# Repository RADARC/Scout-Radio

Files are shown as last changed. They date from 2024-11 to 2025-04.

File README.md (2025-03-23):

# Scout-Radio
Si4732 and Raspberry Pi Pico Radio device for Scouts to build and use to gain badges

Reading and District Amateur Radio Club works withl local Scouts groups and help them in support of their badges and activities

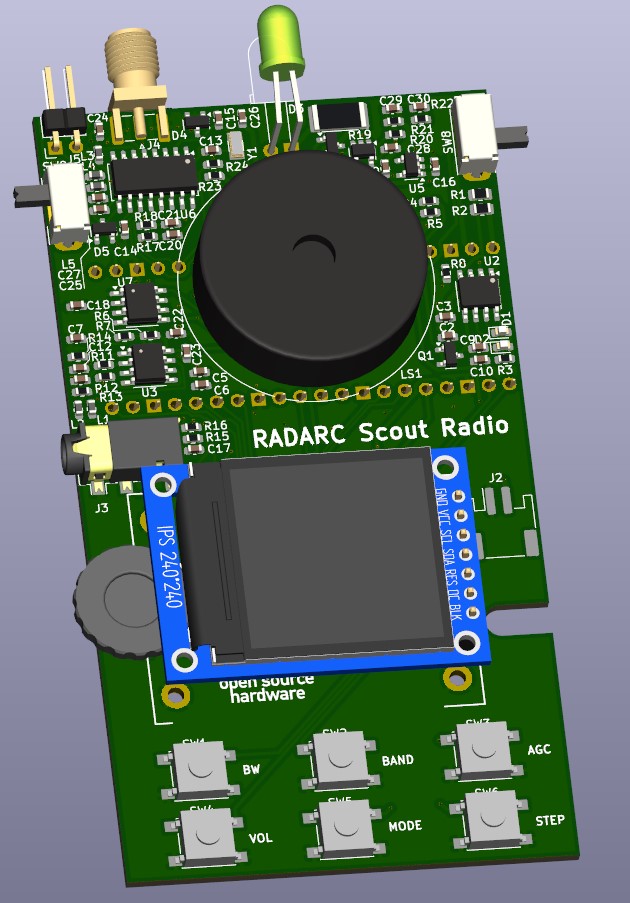
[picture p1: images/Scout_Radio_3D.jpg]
Project Athena 3D


## Objectives:
<ul>
<li>Design and build a radio device with can support Scouts in the following badges
<ul>
<li>[Electronics](https://www.scouts.org.uk/scouts/activity-badges/electronics/)</li>
<li>[Communicator](https://www.scouts.org.uk/scouts/activity-badges/communicator/)</li>
</ul>
<li>Involve Scouts in radio activities</li>
<li>Potential Sponsorship and incresaed local community technology support for Scouts</li>
<li>Interesting Project for RADARC Constructors</li>
<li>Have Fun!</li>
</ul>

## Design Specification
Derived from the RLab Reading Hackspace [Project Athena](https://github.com/reading-hackspace/project-athena)
<ul>
<li>Microprocessor design based on Raspberry Pi Pico Microcontroller</li>
<li>Programmable firmware in CircuitPython and other programming languages via USB</li>
<li>On Board AM and FM Radio</li>
<li>Loudspeaker and audio output</li>
<li>Rotary Encoder and control buttons</li>
<li>Battery powered 3 off AAA, or LiPo with on board charger from USB</li>
<li>Audio output jack</li>
<li>Mixture of surface mount and through hole components. Some components can be factory assembled</li>
<li>Colour LCD display integral</li> 
<li>Optional GPS module</li>
<li>Optional Compass module</li>
<li>Low Cost, under £20</li>
</ul>

## Proposed Design
The following elements are in the prototype design, being commonly available at reasonable cost. Some of these may not be in the final design or optional modules to save cost:

### Raspberry Pi Pico Processor Module
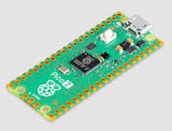
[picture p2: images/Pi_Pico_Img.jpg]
Pi Pico Image


The Raspberry Pi Pico module is based on the RP2040 microprocessor. The module includes flash memory, power supply, crystal clock and a USB interface. It is an easy way to to integrate this processor without detail PCB layout and at attractive cost.
The Pi Pico Module have different variants which are pin compatible. They offer different USB Connectors(Micro-B, USB-C), Wireless and bluetooth integrated, and a higher performance version in the RP2350.
[Pi Pico Data sheet](https://datasheets.raspberrypi.com/pico/pico-datasheet.pdf)

The RP2040 is an ARM Cortex M0+ 32 bit processor which operates at 133MHz and includes a wide range of integrated peripherals.
[RP2040 Data sheet](https://datasheets.raspberrypi.com/rp2040/rp2040-datasheet.pdf)

High quality software support for the RP2040 and Pi Pico Modules is available in C/C++ ([C SDK](https://www.raspberrypi.com/documentation/microcontrollers/c_sdk.html), and [Arduino Pi Pico](https://www.tomshardware.com/how-to/program-raspberry-pi-pico-with-arduino-ide)), and Python([Micropython](https://www.raspberrypi.com/documentation/microcontrollers/micropython.html), and [CircuitPython](https://circuitpython.org/board/raspberry_pi_pico/))

### SiLabs Si4732 AM/FM radio
[Datasheet](https://www.skyworksinc.com/-/media/Skyworks/SL/documents/public/data-shorts/Si4732-A10-short.pdf)

The Si4732 is an integrated AM/FM radio device which is digitally programmable over I2C.
It covers a range of frequencies:
<ul> 
<li>Worldwide FM band support (64–108 MHz) </li>
<li>Worldwide AM band support (520–1710 kHz)</li>
<li>SW band support (2.3–26.1 MHz)</li>
<li>LW band support (153–279 kHz)</li>
</ul>
The radio also supports FM stereo and RDS.
Software patches are available for the device to support SSB and NBFM

### Rotary Encoder and push button controls

A side operated rotary encoder is installed on the prototype, but we might look at lower cost alternatives. There are 6 tactile push button switches which can be used to invoke the various radio functions. These controls can also be used to play simple nintendo like games on the radio.

### Audio Output
The stereo audio audio output from the radio chip is amplified to provide an output to headphones of external speakers. This is then further amplified to drive an on board loudspeaker.
The output from the radio chip is also fed to the ADC inputs on the Pi Pico to enable the Pi Pico to provide USB or Bluetooth feed to an external program such as WSJT-X. The Pi Pico may be able to decode locally digital protocols such as FT8 and display locally.
The Pi Pico also provides a PWM audio output for beeps, morse code, and music for simple games.

### 1.3 inch IPS Colour LCD Display
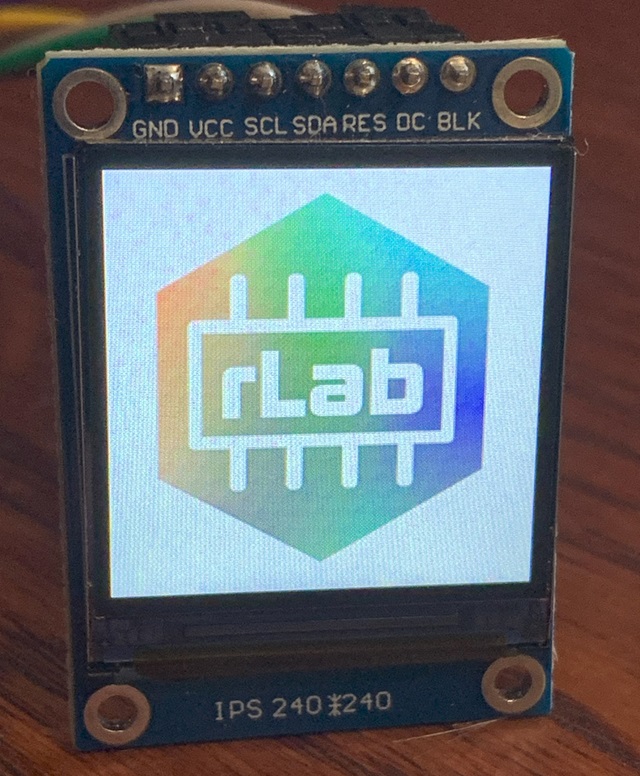
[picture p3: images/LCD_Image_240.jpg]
LCD Image


A colour LCD display was chosen for the device. Limited space allows for a [240 by 240 pixel 1.3 inch IPS display](https://www.smart-prototyping.com/1_3-inch-TFT-IPS-Display-Module-ST7789-SPI-240-240).
The module is based on the ST7789 display IC and is supported by both Micropython and CircuitPython grahics libraries.

### Torch

A high intensity white LED is provided under processor control to be used as a torch or for visual signalling.

### Compass Option
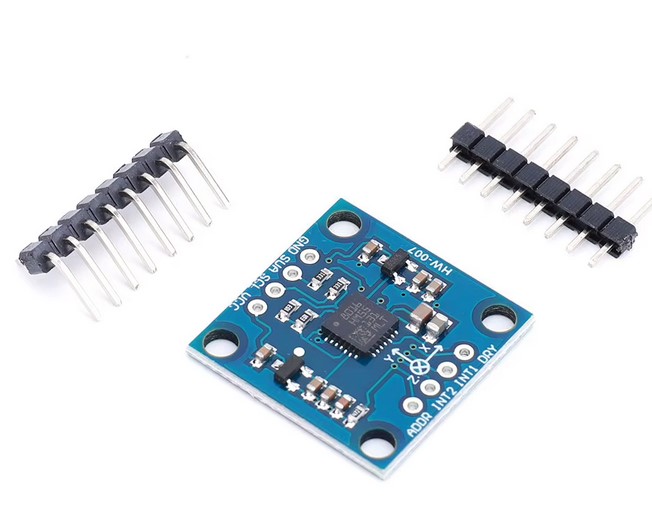
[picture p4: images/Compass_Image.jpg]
Compass Image


An optional compass module based on the LSM303 magnetometer, Compass and accelerometer device can be fitted.

### GPS Option
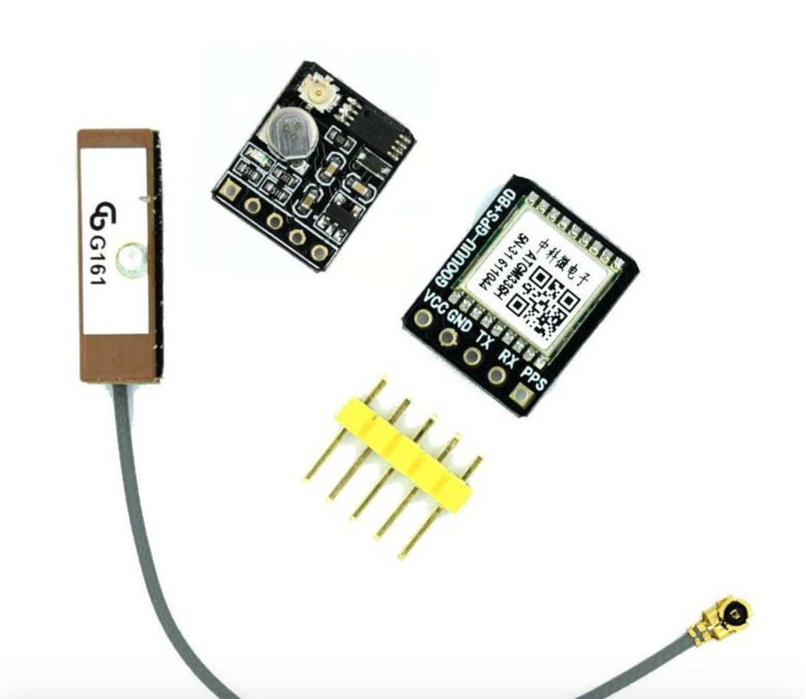
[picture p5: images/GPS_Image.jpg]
GPS Image


An optional GPS module based on the ATGM336H GPS receiver can be fitted 

## Costs
The following costs are based on the JLCPCB prototype build of five units.
All costs are in UK pounds and include shipping and taxes

### Component Costs
| Item | Cost £ |
|---|---|
|Placed components| 8.68| 
|Unplaced components| 8.44|
||--------|
|Total £| 17.12|

The above component cost includes PCB, SMT components, Pi Pico, display and all switches and connectors. I does not include a case.
The placed components were placed by JLCPCB. This cost is dominated by the radio chip and rotary encoder, better sourcing could easily get the component cost under £15.

### Optional Components
| Item | Cost £ |
|---|---|
|LiPo Battery | 2.1|
|SMA antenna| 2.59|
|Compass module| 2.75|
|GPS Module|  2.92 |

### Build Costs
The build costs are again based on the five off prototype, so maybe not very representative of a larger batch. I excluded from the build the through hole components to save cost, also a couple of components that they did not have in stock.
Build costs are driven by a mix of fixed costs per order, setup, solder stencil, etc. Also Costs per board and joint.There are then costs related to what components are used. Common components are already mounted on the pick and place machine and have low cost per component ( fraction of cent). Less common components are often low cost, but we pay $3 per component type to load the component spool to the pick and place, this cost often dominates the assembly costs.
Assembly of through hole components and components and edge mounted components is possible but would attract increased cost.

For the five prototypes:

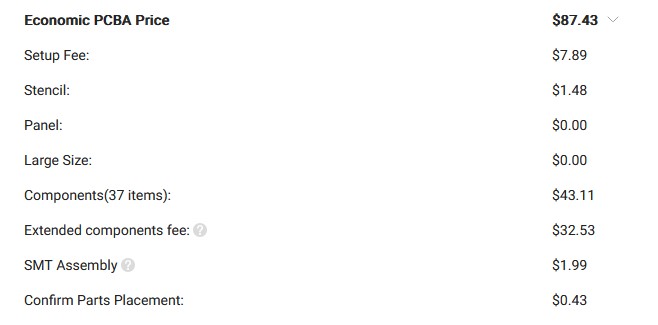
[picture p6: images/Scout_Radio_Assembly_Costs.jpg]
Assembly Pricing


The placed component costs can be excluded, so $44.32 for five. With tax and shipping this is £11.08 per board. Rather expensive at prototype level, but for for a decent board volume (25) when I run through the pricing calculator I get £2.20 per board.

## PCB Files

## Installing Software
``` reinstallsys.sh ```
installs a system from scratch including Circuit Python. Runs on linux only atm.

## Software Project Plan, 12th March 2025.
Tasks are either small, medium or large (S/M/L)

In priority order:
* Sort out test code and harness for si4735 driver (done)
* Design and implement a software installation process for target hardware, automating wherever possible (M, done)
* Document possible use cases (M)
* Provide example higher level libraries and applications (M)
* Design and implement standalone POST/BIST for target hardware (M)
* Design and implement production test software. Possibly involves use of
  laptop. Scouts need to know if what they have built works :-) (M)

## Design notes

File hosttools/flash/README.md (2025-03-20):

# tools to re-install RPI pico boards with circuit python or micro python
```./installcircuit.sh```
or
```./installmp.sh```

BEWARE ALL FILES WILL BE DELETED ON THE TARGET SYSTEM

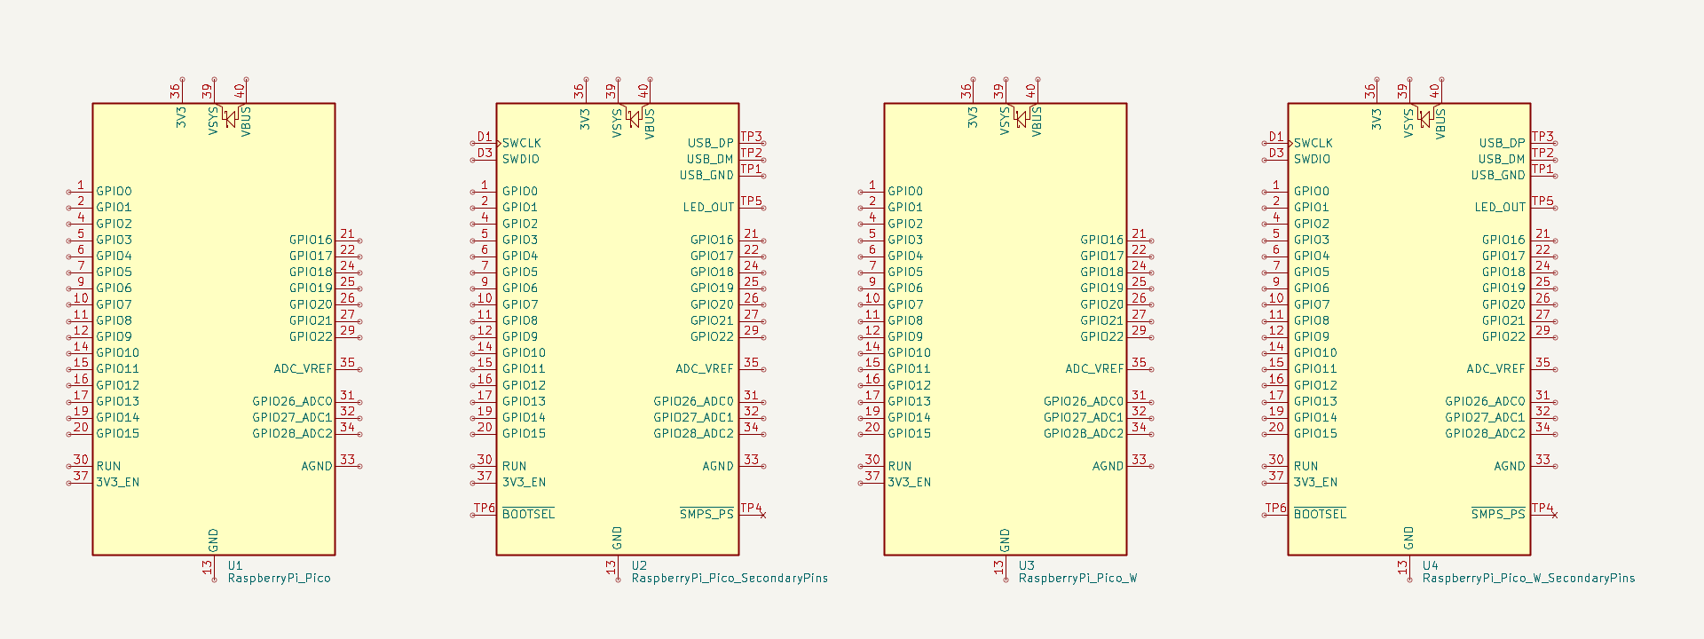
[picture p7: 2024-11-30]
Kicad/Scout_radio/ki-lime-pi-pico-2.1.2/_md-assets/images/schematics.png

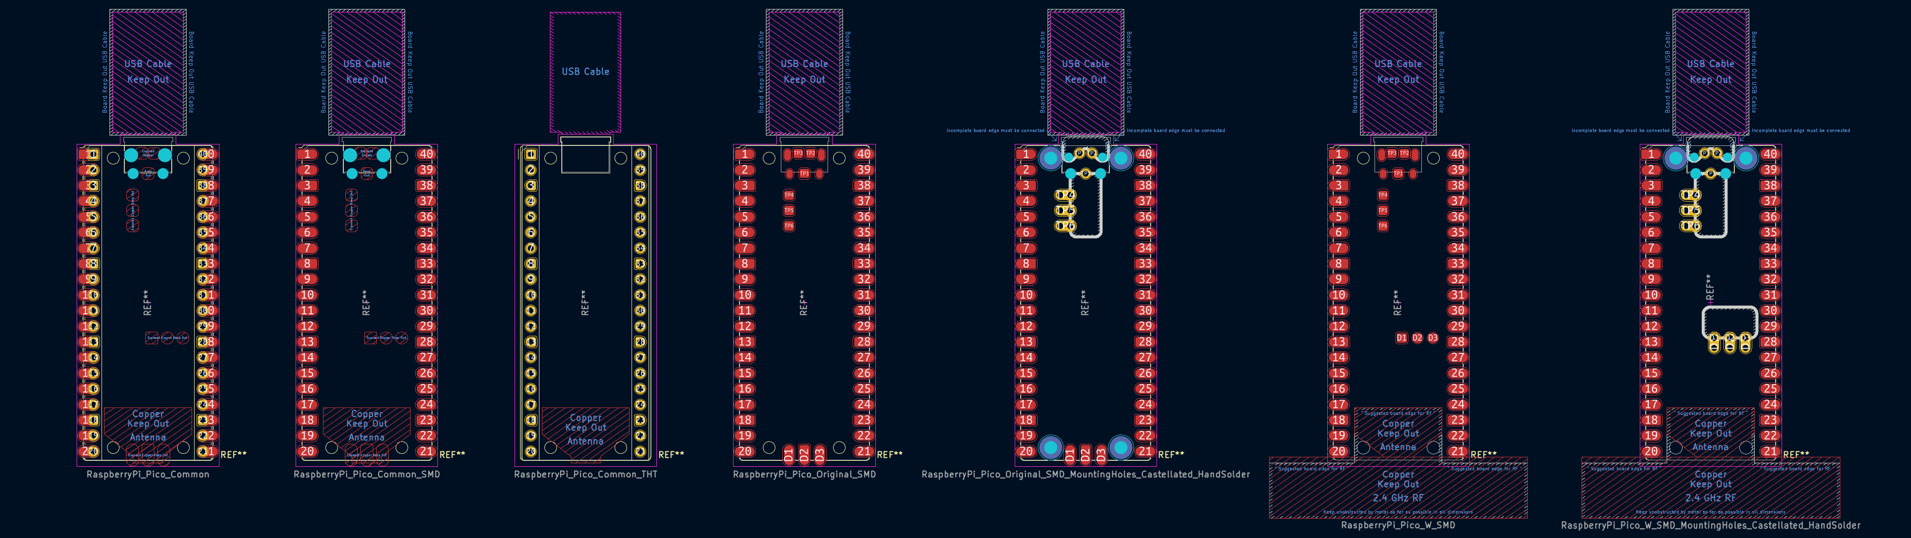
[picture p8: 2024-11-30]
Kicad/Scout_radio/ki-lime-pi-pico-2.1.2/_md-assets/images/footprints.png

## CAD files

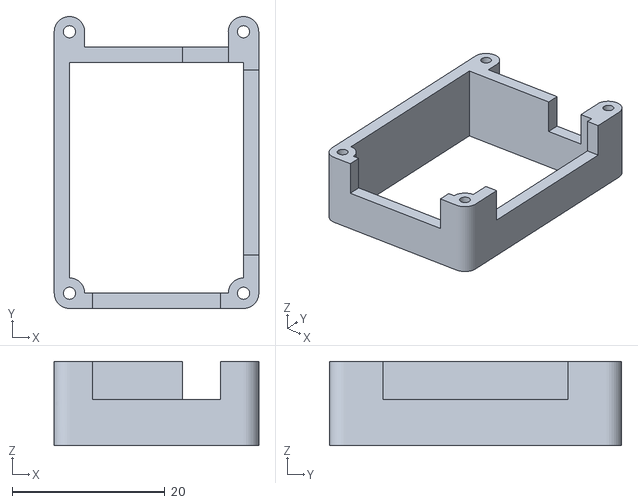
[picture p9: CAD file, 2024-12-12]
CAD/Display Scout.stl
26.8 x 38.2 x 11.0

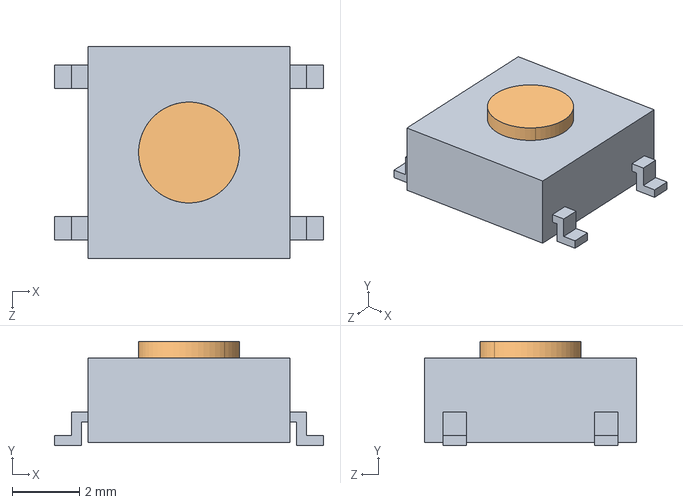
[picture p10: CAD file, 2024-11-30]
Kicad/Scout_radio/3D_Models/B3FS_1000.step
8.00 x 3.10 x 6.30 mm
B3FS_1000_BASE
B3FS_1000_BUTTON

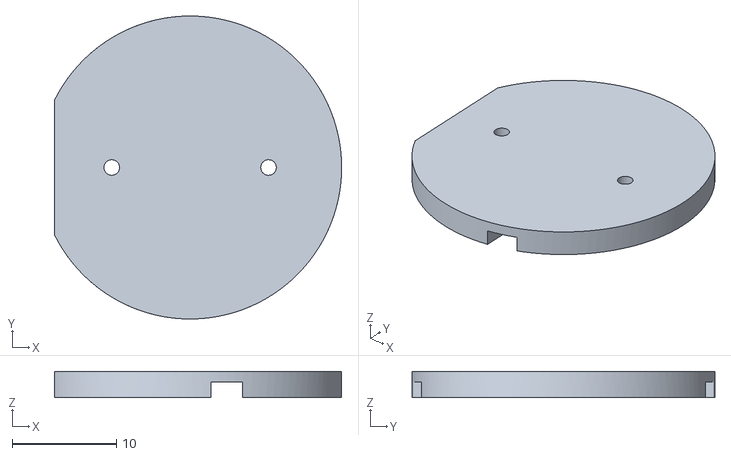
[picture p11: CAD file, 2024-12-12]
CAD/Speaker Mount.stl
27.5 x 29.0 x 2.50

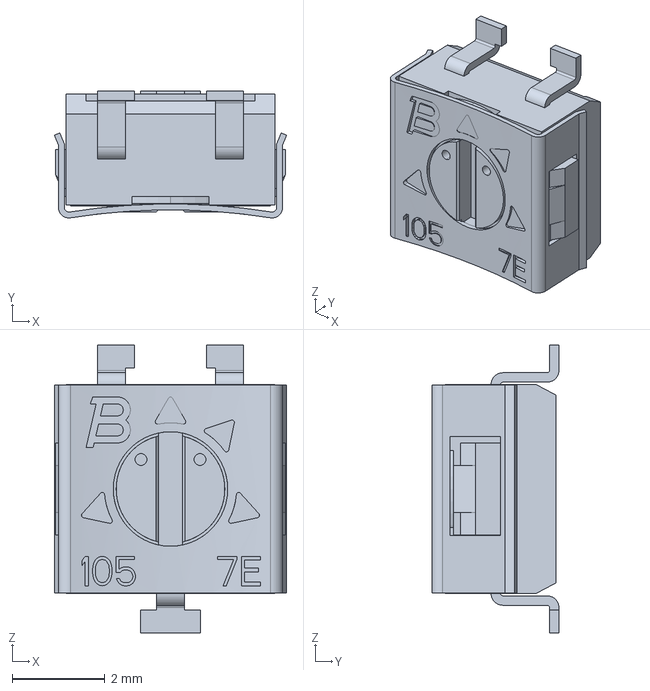
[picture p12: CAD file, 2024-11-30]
Kicad/Scout_radio/3D_Models/3314G1.stp
5.00 x 2.73 x 6.20 mm

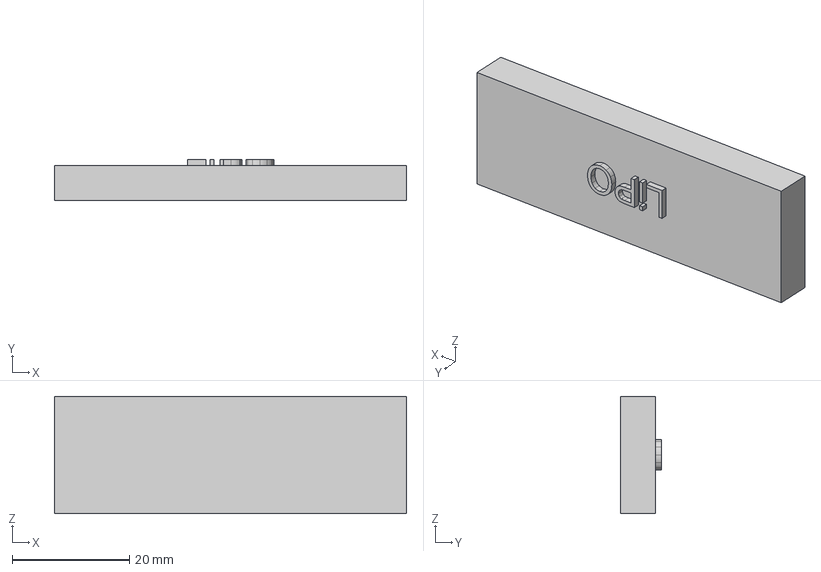
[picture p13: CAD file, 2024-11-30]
Kicad/Scout_radio/3D_Models/Lipo 602006 v1.step
60.0 x 7.00 x 20.0 mm

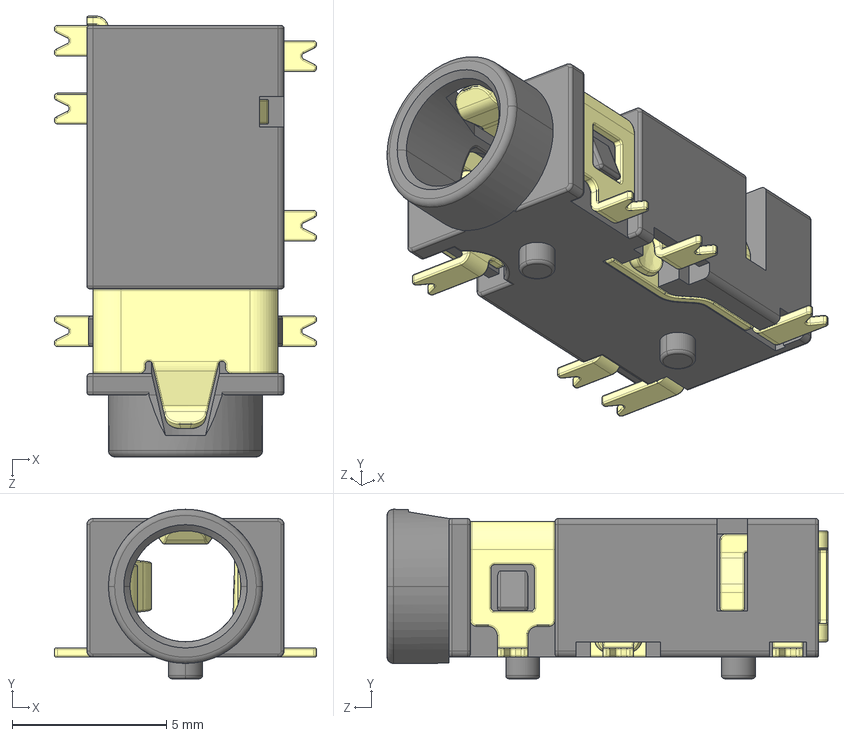
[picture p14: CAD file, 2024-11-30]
Kicad/Scout_radio/3D_Models/PJ311D_WPos.STEP
8.50 x 5.50 x 14.3 mm
001^PJ311D_WPos
002^PJ311D_WPos
003^PJ311D_WPos
004^PJ311D_WPos
005^PJ311D_WPos
006^PJ311D_WPos
007^PJ311D_WPos

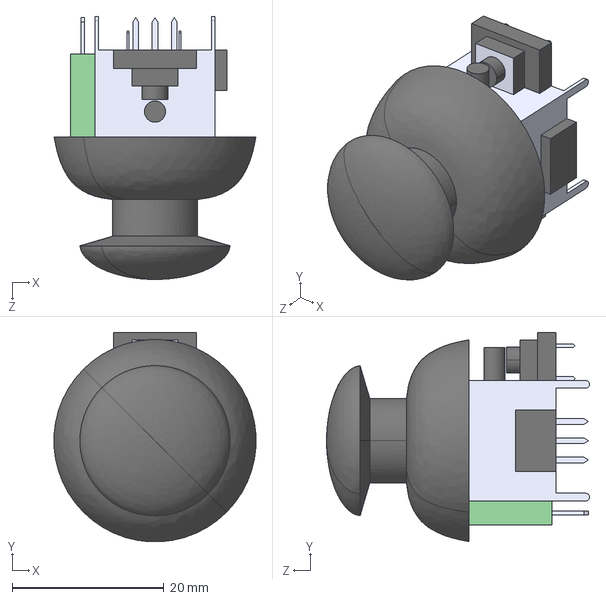
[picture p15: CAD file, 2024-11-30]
Kicad/Scout_radio/3D_Models/9032.STEP
26.6 x 27.6 x 34.7 mm

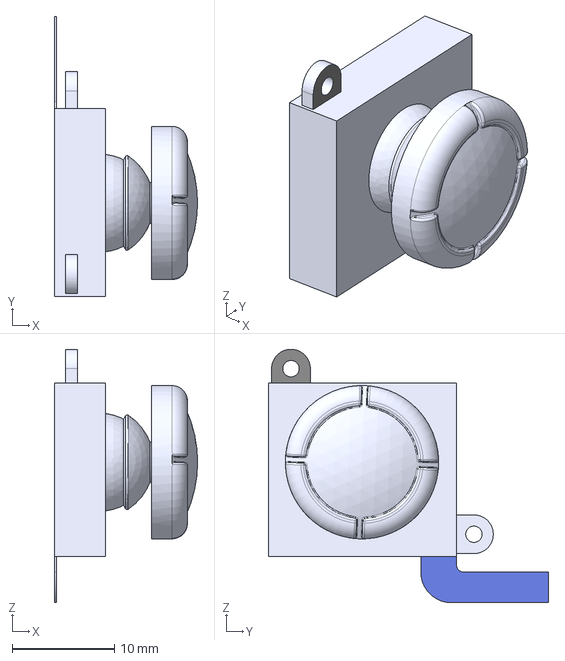
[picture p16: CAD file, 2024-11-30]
Kicad/Scout_radio/3D_Models/Switch JoyCon joystick v2.step
14.0 x 27.4 x 24.8 mm

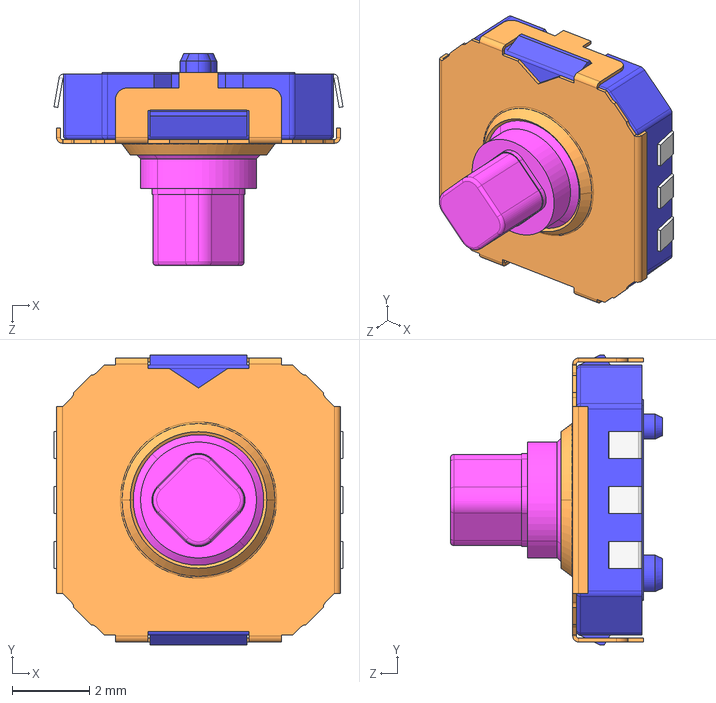
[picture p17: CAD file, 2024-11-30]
Kicad/Scout_radio/3D_Models/SKRHAB.STEP
7.48 x 7.50 x 5.50 mm

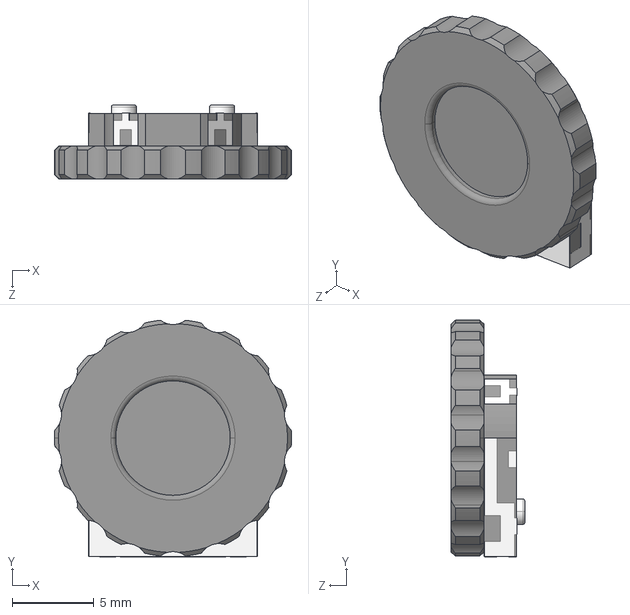
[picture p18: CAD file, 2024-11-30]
Kicad/Scout_radio/3D_Models/User Library-SIQ-02FVS3-1.STEP
14.5 x 14.5 x 4.50 mm

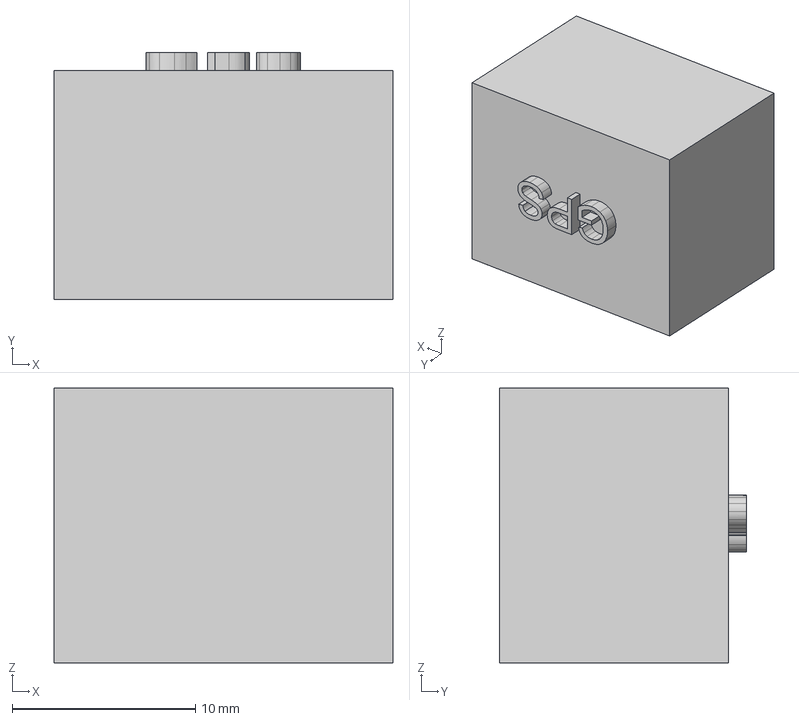
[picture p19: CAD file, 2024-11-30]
Kicad/Scout_radio/3D_Models/GPS v2.step
18.5 x 13.5 x 15.0 mm

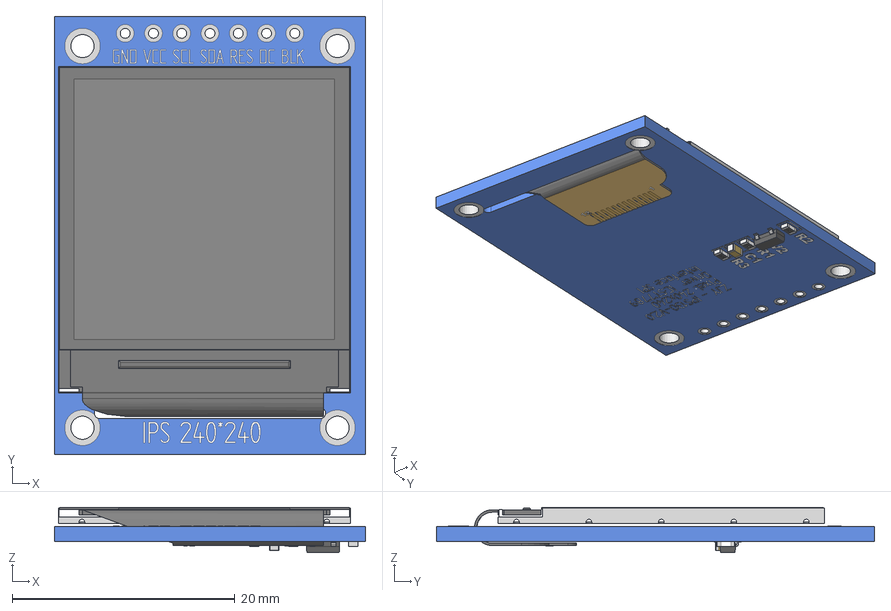
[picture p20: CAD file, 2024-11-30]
Kicad/Scout_radio/3D_Models/1.3 TFT IPS.stp
27.9 x 39.4 x 4.06 mm
1.3 TFT IPS - Board
1.3 TFT IPS - Flush Reverse Mount
0603 Resistor x 3
0603 Capacitor
SOT-23

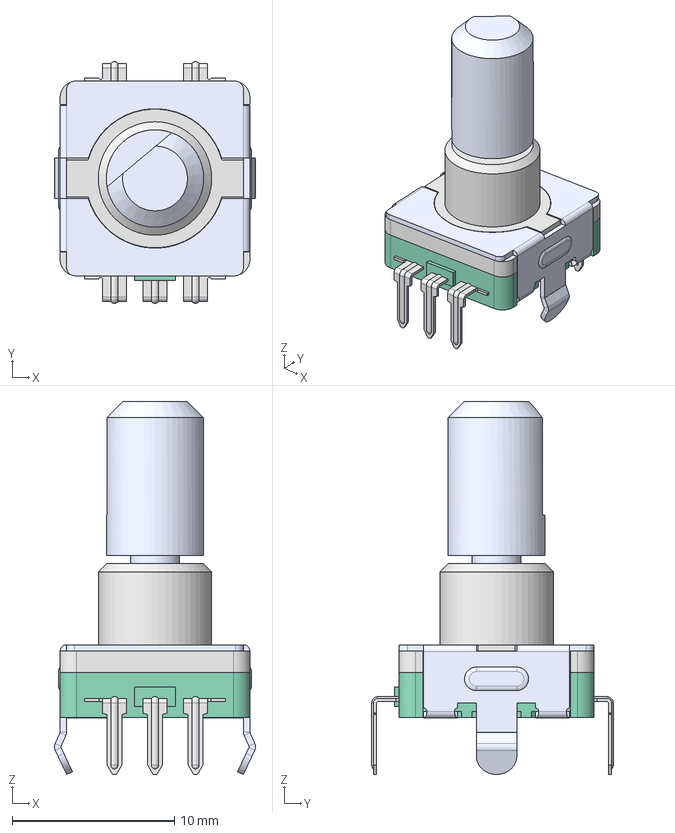
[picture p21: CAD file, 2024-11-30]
Kicad/Scout_radio/3D_Models/EC11-THT.step
12.4 x 14.9 x 23.0 mm
Lb5
15F
EC11-Housing-THT

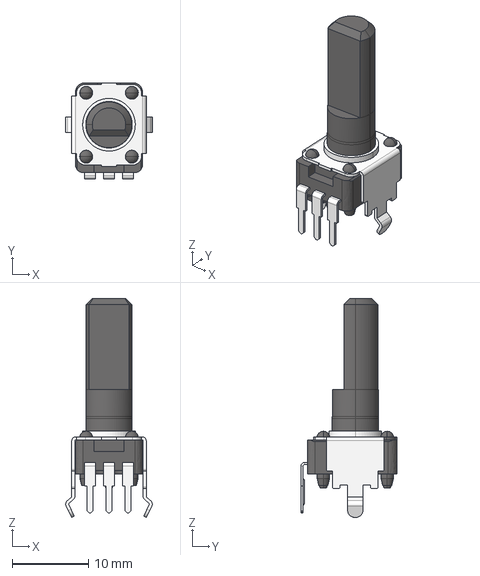
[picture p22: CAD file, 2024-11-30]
Kicad/Scout_radio/3D_Models/RK09K1130AH1.STEP
11.4 x 12.7 x 28.8 mm

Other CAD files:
Kicad/Scout_radio/3D_Models/3214G.stp
Kicad/Scout_radio/3D_Models/EVQ-WKA001--3DModel-STEP-56544.STEP
Kicad/Scout_radio/3D_Models/18650 Battery Holder v5.step
Kicad/Scout_radio/KiCad-RP-Pico/SketchUp Model/Pico.skp
Kicad/Scout_radio/SW_SKRHABE010_SMD.blend

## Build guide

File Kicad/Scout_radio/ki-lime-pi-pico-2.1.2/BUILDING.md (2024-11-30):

**Instructions for building from source**
===========================================

> *Note that this project was largely leveraged for becoming more familiar with various aspects of KiCad, FreeCAD, and the Raspberry Pi Pico, and certain files may use exploratory workflows as a result.*

&nbsp;

# Development Environment

  Parametric models exported using [FreeCAD 0.21.2](https://github.com/FreeCAD/FreeCAD/releases/tag/0.21.2) with the [KiCad StepUp 12.2.6](https://github.com/easyw/kicadStepUpMod/tree/a7da10da12e405d106e1e9eb551444a289859ee8) workbench addon

  If you plan on committing changes to the .FCStd document and want (somewhat) trackable commits, then from the repository root call:

  ```bash
  mkdir -p .git/hooks
  cp .githooks/pre-commit.sh .git/hooks/pre-commit
  git config --local core.hooksPath .git/hooks
  ```

  *(If you are already using a `pre-commit` git hook, then manually add the content of `pre-commit.sh` to the existing hook instead)*

  > *Copying the file at a known state curbs the security concerns of remote changes to a hook.  Always audit scripts before using them.*

  Exported VRML models modified in [VSCodium 1.74.3](https://github.com/VSCodium/vscodium/releases/tag/1.74.3.23010)

  KiCad symbols and footprints exported using [KiCad 8.0.3](https://github.com/KiCad/kicad-source-mirror/releases/tag/8.0.3)

&nbsp;

# Symbols and Footprints

  KiCad symbols and footprints are already in the appropriate directories, so nothing needs to be done to prepare them for export.

&nbsp;

# Models

<details><summary>Regarding parametric colours</summary>
  
  > *Model faces are parametrically coloured via boolean operations between parts of varying diffuse colours.  To alter source colours for the board, see `Parametric_Source > Boards_Source > Parametric Board Colour Sources` in the `Tree view` panel and modify each Body's `Appearance`.  To alter source colours for components, be sure to modify the `Appearance` of the source Bodies **directly**, which are contained within the compounds/part containers in `Parametric_Source > Pico_Components_Source`.  Modifying the `Appearance` of the compounds/part containers or setting parts' face colours with `Set Colors...` will **not** parametrically populate.*
  >
  > *Note that as of FreeCAD 0.20.2 changing the sources of the colours does not automatically populate down all the dependent objects.  To get around this if you make any colour changes, when you are ready to export be sure to recompute the entire document as detailed below.  This should successfully populate the parametric colours across all dependent objects.*
  
</details>

  ### General

  - Open the models source file at `.../ki-lime-pi-pico/models/RaspberryPi_Pico_Variations.FCStd` in FreeCAD

    > Note: ~~If reproducible builds are important, be sure to stash any local changes to the file and reopen it before building so that you are recomputing from a known commit.~~  
    > ~~This is particularly important if you are using the `pre-commit` git hook described above.~~  
    > There is inconsistent noise generated with each recompute/export.  As a result, reproducible builds are not possible as built models will slightly differ each time.
  
  - If not already marked to recompute, in FreeCAD's `Tree view` panel `right-click` on the root document name `RaspberryPi_Pico_Variations` and select `Mark to recompute`

  - Click `Edit > Refresh` (or press `F5`) to recompute the entire document

  ### VRML

  - Enter the KiCad StepUp addon workbench from the drop-down menu at the top of the window

  - In FreeCAD's `Tree view` panel, locate the contents of the folder `Export > KiCad Model Outputs > VRML - Manually Coloured Clones`

  - If you are building from an official release commit, select the `Clone` you wish to export to a VRML file for KiCad (for example: `RaspberryPi_Pico`)  
    If you are building from a custom modification, you will likely need to recreate the `Draft Clones` from the parametrically coloured `Compounds` in `Export > KiCad Model Outputs > STEP - Parametrically Coloured Compounds`

    <details><summary>Additional information regarding clones and colours</summary>
      
      > *KiCad StepUp provides a selection of fully-featured materials that can be exported to VRML files.  Although the selection is limited, it provides convenient labelling of materials that can be edited later.  I have created `Clones` of each variation (which as of FreeCAD 0.20.2 do **not** parametrically preserve colour) and pre-set each face colour to align with colours defined within KiCad StepUp.*
      >
      > *Note that if you change geometry in any way which alters the number or topological location of faces anywhere within the model, these pre-set `Clones` will no longer be coloured appropriately*
      >
      > *You can always export from the parametrically coloured `Compounds` in `Export > KiCad Model Outputs > STEP - Parametrically Coloured Compounds`, just needing to set the export colours in KiCad StepUp each time as they will be reset upon recomputes.*
      
    </details>

  - Click on KiCad StepUp's `Export 3D Model` button (a graphic of a black 6-pin IC with a green arrow pointing down and to the right)

  - When prompted, I have used the values of `0.03 Mesh Deviation` and `0.5 creaseAngle` (old default values) and I find the results to be acceptable

  - If you are building from an official release commit, simply accept all the KiCad StepUp colour association prompts  
    If you are building from newly created `Clones`, you will need to manually set KiCad StepUp's colour associations.
    
    <details> <summary> Additional information regarding KiCad StepUp colour association </summary>
    
      > This part can be frustrating, as many parts appear off-white but are different materials.
      > When I built it, there are some colours which are automatically associated to a named material in KiCad StepUp; you shouldn't have to alter those.  
      > The remaining non-automatic colours broadly presented themselves in the following order:
      >
      > - `metal silver` (soldered pads)
      > - `pcb green`
      > - `light brown label` (FR4 core)
      > - `yellow body` (gold pins)
      > - `brown body` (caps)
      > - `resistor black body` (res/diode)
      > - `led white` (led lens)
      > - `light brown body` (led board)
      > - `green body` (led phosphor)
      > - `metal grey` (oscillator/wifi package)
      >
      > If this list doesn't appear to be accurate for you, then you can always set each colour to a high-contrasting material, and then select the appropriate material association in a second round of exporting.

    </details>

  - Repeat this for all `Clones`

  - Prepare a powerful text editor for bulk file editing

    <details> <summary> Specific instructions for preparing VSCodium/VSCode</summary>

      - Open a new VSCode-based instance

      - Select `File > Open Folder...`

      - Navigate to the directory `.../ki-lime-pi-pico/`

      - Select the folder `models/` and click `Select Folder`

      - Open each `.wrl` file by `double-clicking` each file in the `Explorer` pane

      - Select the magnifying glass on the left to open the `Search` pane

      - Expand the search box with the arrow to its left to reveal its find-and-replace functionality

      - Click the `...` in the bottom-right of the find-and-replace fields to expand additional options

      - Select the graphic of an open book in the `files to include` field to only process files which are currently open

    </details>

  - Find and replace the following material names in the newly created `.wrl` files:

    > *Be sure **not** to replace these material names in `MaterialsList.txt`!*

    | Original material   | Replace with
    |:-------------------:|:------------:
    | `PLASTIC-YELLOW-01` | `FINISH-GOLD`
    | `MET-SILVER`        | `FINISH-SILVER`
    | `RES-SMD-01`        | `IC-BODY-EPOXY-02`
    | `CAP-CERAMIC-06`    | `CAP-CERAMIC-01`
    | `MET-01`            | `FINISH-TIN`
    | `IC-LABEL-01`       | `BOARD-FR4-NATURAL`
    | `BOARD-GREEN-02`    | `MASK-PINE-GREEN`
    | `RES-THT-01`        | `MASK-LIGHT-TAN`
    | `LED-WHITE`         | `LED-LENS-CLEAR`
    | `PLASTIC-GREEN-01`  | `EMISSIVE-GREEN-PHOSPHOR`
  ##  
  - Finally, replace the default KiCad StepUp material definitions at the start of each `.wrl` file with the expanded list of materials found in `MaterialsList.txt`

    > *In VSCode-based editors, selecting `Match Case` in the search allows for the large blocks of material definition text to successfully be found and replaced*

    ---

  &nbsp;

  > *KiCad StepUp will automatically generate STEP files with limited hierarchy, part naming, and colour information as a result of the process above, so next we will export STEP models with more detailed information.*

  > *As of the time of writing, KiCad does not appropriately handle exporting part face colours when the component's STEP file uses assemblies.  To get around this, we will export our STEP models as `Compounds` for KiCad.  This will still result in limited hierarchy and part naming information, but will at least preserve face colours (excluding transparency) and discrete sub-components.*

  ### STEP (for KiCad)

  - In FreeCAD's `Tree view` panel, shift focus to the contents of the folder `Export > KiCad Model Outputs > STEP - Parametrically Coloured Compounds`

  - Manually select the root body you wish to export (for example: `RaspberryPi_Pico_Compound`)

  - Press `Ctrl + E`, or select `File > Export`

  - For ease, ensure the directory matches where KiCad StepUp exported its files to:
    `.../ki-lime-pi-pico/models/`

  - Ensure file type `"STEP with colors (*.step *.stp)"` is selected

  - Select the name of the already-generated model you intend to replace (for example: `RaspberryPi_Pico.step`)

  - Select `Save`, and select `Yes` when asked to replace the existing file

  - Repeat this for all models

  - Once all 3D models have been exported as `.wrl` and `.step` files, navigate to:

  ```
  .../ki-lime-pi-pico/models/
  ```

  - And **copy** (don't remove!) all `.wrl` and `.step` files to:

  ```
  .../ki-lime-pi-pico/kicad/project-libraries/RaspberryPi_Pico/Module_RaspberryPi_Pico.3dshapes/
  ```

  ---
  > *In addition to these KiCad models, we can also export a second set of STEP files to a supplemental directory, in the event any users have a need for the fully-featured assemblies.  Feel free to skip this section if all you need is a standalone KiCad library.*

  ### STEP (fully featured supplement)

  - In FreeCAD's `Tree view` panel, navigate into the folder `Export > STEP Assembly`

  - Manually select the root body you wish to export (for example: `RaspberryPi_Pico_STEP`)

  - Press `Ctrl + E`, or select `File > Export`

  - For ease, ensure again the directory matches where KiCad StepUp exported its files to:
    `.../ki-lime-pi-pico/models/`

  - Ensure file type `"STEP with colors (*.step *.stp)"` is selected

  - Select the name of the already-generated model you intend to replace again (for example: `RaspberryPi_Pico.step`)

  - Select `Save`, and select `Yes` when asked to replace the existing file

    > *As a result of using empty `Group` folders as a source of parametric part/feature naming, exporting these parts will result in an expected warning in the `Report view`.*

  - Repeat this for all models

  - Once these 3D models have been exported as `.step` files, navigate to:
  ```
  .../ki-lime-pi-pico/models/
  ```

  - And copy all `.step` files to:

  ```
  .../ki-lime-pi-pico/models/RaspberryPi_Pico_STEP/
  ```

  ### File cleanup

  - Navigate to `.../ki-lime-pi-pico/models/`

  - Delete the previously copied `.wrl` and `.step` files, as they are no longer needed in this directory

&nbsp;

# Final recommendations

As desired, navigate to our source's root directory:

```
.../ki-lime-pi-pico/
```

Append, replace, or otherwise modify files such as `LICENSE.txt`, `ATTRIBUTION.md`, and `README.md` to appropriately reflect your needs.

Copy the desired files *(for example, I include all three of `LICENSE.txt`, `ATTRIBUTION.md`, and `README.md` with the final build)* to:

```
.../ki-lime-pi-pico/kicad/project-libraries/RaspberryPi_Pico/
```

*I prefer to remove the references to images in the built library's `README.md` once it's copied here to keep it clean and compact.*

If you are also exporting the fully-featured supplemental STEP models, copy the desired files *(for example, I include `LICENSE.txt` and `ATTRIBUTION.md`)* to:

```
.../ki-lime-pi-pico/models/RaspberryPi_Pico_STEP/
```

&nbsp;

# **All done!** 🎉

Your completed library to reference, copy, and distribute as you wish can be found at:

```
.../ki-lime-pi-pico/kicad/project-libraries/RaspberryPi_Pico/
```

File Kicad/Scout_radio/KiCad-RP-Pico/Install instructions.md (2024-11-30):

# Install instructions

## 1. Copy the files locally

Copy the `RP-Pico Libraries` folder wherever you like on your computer.

## 2. Install the Raspberry Pi Pico board schema symbol

Use the `KiCad | Preferences | Manage Symbol Libraries...` command to manage the symbol library:



then select the global tab and click on the folder button:



navigate to the `RP-Pico Libraries` folder, select the `MCU_RaspberryPi_and_Boards.kicad_sym` file and open it:



et voilà, the first step is completed:



You can now close the symbol libraries manager window.

## 3. Install the Raspberry Pi Pico board footprint

You can use a similar approach to add the footprint to the footprint libraries manager, but I've found some issues that I've solved using the footprint editor, so here are the steps I suggest you to follow:

Open the footprint editor



wait for the footprints to load... then use the `File | Add Library` command:



confirm the `Global` choice:



and select the `MCU_RaspberriPi_and_Boards.pretty` folder (yes, the folder represent a footprint library on KiCad):



Now the library is installed on KiCad with the Raspberry Pi Pico footprint (double click on it to see it on the editor pane):



Don't close the windows as the next step start from here.

## 4. Install the Raspberry Pi Pico board footprint 3D visual

If not already open, open the the footprint editor

symbol library manager

double click on the `RPi_Pico_SMD_TH` footprint from the `MCU_RaspberriPi_and_Boards` library and then click on the `Footprint properties` icon:



In the footprint properties window, first select the `3D Settings` tab. Please note that the preview shows only the PCB board with the footprint added on step 3, without any 3D representation of the Raspberry Pi Pico board. Now click on the folder icon to add the 3D model:



Navigate to the `RP-Pico Libraries` folder, select the `Pico.wrl` file and wait until the model is shown in the right panel, then confirm with OK:



The model is already scaled and translated to match the footprint:



now close the `Footprint Properties` window, and the `Footprint Editor`, obviously saving the changes.

## Conclusion

Now that you've installed the schema and footprint and added the 3D model to the footprint, you can use the Raspberry Pi Pico board on your KiCad projects.

I've also added a test KiCad Project on the `Test` folder, that you can use to see an example of it.

Have fun!

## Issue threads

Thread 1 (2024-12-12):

Hardware: SDA and SCL pins are swapped between Pi Pico and Si4732

ribbotson, 2024-12-12:
Kicad files updated to have SCK on GPIO19 and SDA on GPIO18

Closed 2025-04-19.

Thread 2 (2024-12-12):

Hardware: Footprint of LISM303DHLR Magnetometer and Accelerometer is incorrect

ribbotson, 2024-12-12:
Footprint does not fit module pin spacing

ribbotson, 2025-04-19:
Have moved to different LISM303DHLC GY-511 module. Kicad updated.

Closed 2025-04-19.

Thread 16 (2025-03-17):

(S) improve test.py for si4735; consider an explicit software/si4735 component.

johngumb, 2025-03-17:
Currently test.py in radio prints a lot of stuff but doesn't actually make sure the chip is doing the right thing.

This can be improved.

It may make sense to create a software/si4735 component and have the install.py put si4735.py into /lib on target.

johngumb, 2025-03-27:
si47xx_test.py created.
Keep in software/Radio for now.

Closed 2025-03-27.

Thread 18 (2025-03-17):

Consider standardising on pico W

johngumb, 2025-03-17:
Consider standardising on pico W.

More fun for scouts and us.

ribbotson, 2025-03-17:
I have Pico W, Pico 2 and Pico 2 W with headers if you want to try. Interested to see if the 2.4GHz interferes with the radio.
There were some concerns about an internet or other network (meshtastic) connected device for young people. The other Picos should just be plug in replacements.

johngumb, 2025-03-17:
Thanks Richard. I suppose we could lock down internet connectivity. There again no doubt there are clever scouts. Got some reading up to do on exactly what the W variant can do (bluetooth, BLE etc.).

johngumb, 2025-03-17:
I'd (almost) be prepared to lock down to bluetooth/BLE if necessary to get W variant.

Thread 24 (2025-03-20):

(S) improve installcircuit.sh, possibly rewrite in python

johngumb, 2025-03-20:
installcircuit.sh is useful to reflash pico boards. Could use some love to improve user interaction; review "press any key to continue" and look for circuit python mount appearing to verify install process is complete.

johngumb, 2025-03-26:
looks ok-ish now

Closed 2025-03-26.

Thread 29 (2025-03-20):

(S) remove duplicated code in installmp.sh and installcircuit.sh

johngumb, 2025-03-20:
hosttools/flash/installmp.sh and installcircuit.sh do very similar things for installing micro and circuit python.

remove duplicated code somehow.

johngumb, 2025-03-20:
fixed in 05e01d3e326

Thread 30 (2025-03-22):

(S) Create a common software interface to scout board low level hardware

johngumb, 2025-03-22:
provide a single interface onto scout radio hardware (switches, rotary encoders, displays etc.)

rather than each app having to create Switches, encoders etc.

This ensures resources are created consistently and correctly avoiding code duplication,

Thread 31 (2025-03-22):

(S) clean up run.py minicom interaction

johngumb, 2025-03-22:
python run.py --minicom

currently relies on the command "minicom ACM0" working. Consider creating a temporary .minirc minicom initialisation file with the settings we need.

johngumb, 2025-03-23:
fixed in 2a9a36ff

Closed 2025-03-23.

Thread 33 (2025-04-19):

Hardware: Circuit for MOSFET for battery isolation is wrong

ribbotson, 2025-04-19:
Circuit update to drive gate of Mosfet properly from USB power and added pull down

ribbotson, 2025-04-19:
Kicad updated

Closed 2025-04-19.

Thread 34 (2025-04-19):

hardware: Charge circuit not working properly

ribbotson, 2025-04-19:
Charge does not end

ribbotson, 2025-04-19:
Charge current resistor is too low (1k) increase to 2.2K.

Closed 2025-04-19.

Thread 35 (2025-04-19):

hardware: Torch unstable

ribbotson, 2025-04-19:
There is no pull down on the gate of the torch LED

ribbotson, 2025-04-19:
Added pulldown to gate of Torch LED

Closed 2025-04-19.

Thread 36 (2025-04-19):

Hardware: Add 1PPS output from GPS as input to Pi Pico

ribbotson, 2025-04-19:
Would be of value for frequency stability

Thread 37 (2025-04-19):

Hardware: Simplify RF input and remove switch

ribbotson, 2025-04-19:
We only have the SMA antenna connector and no other antenna, so switch not needed. We can either eleiminate or add a PCB antenna as a rear back panel.

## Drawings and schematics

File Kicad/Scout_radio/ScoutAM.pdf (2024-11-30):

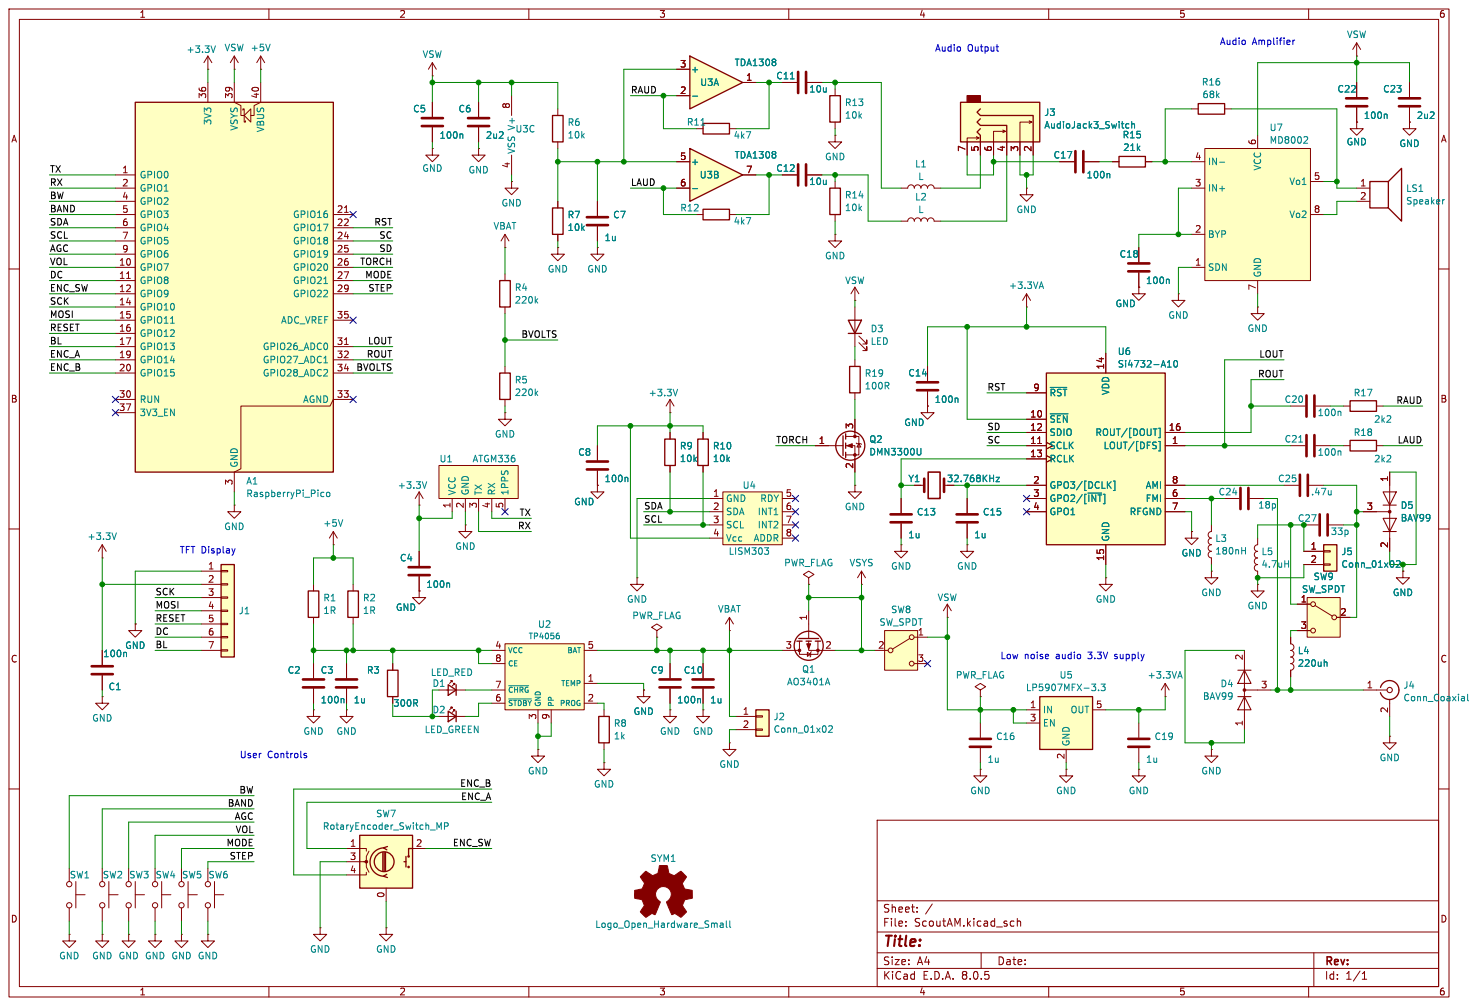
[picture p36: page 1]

Audio Amplifier Audio Output R3

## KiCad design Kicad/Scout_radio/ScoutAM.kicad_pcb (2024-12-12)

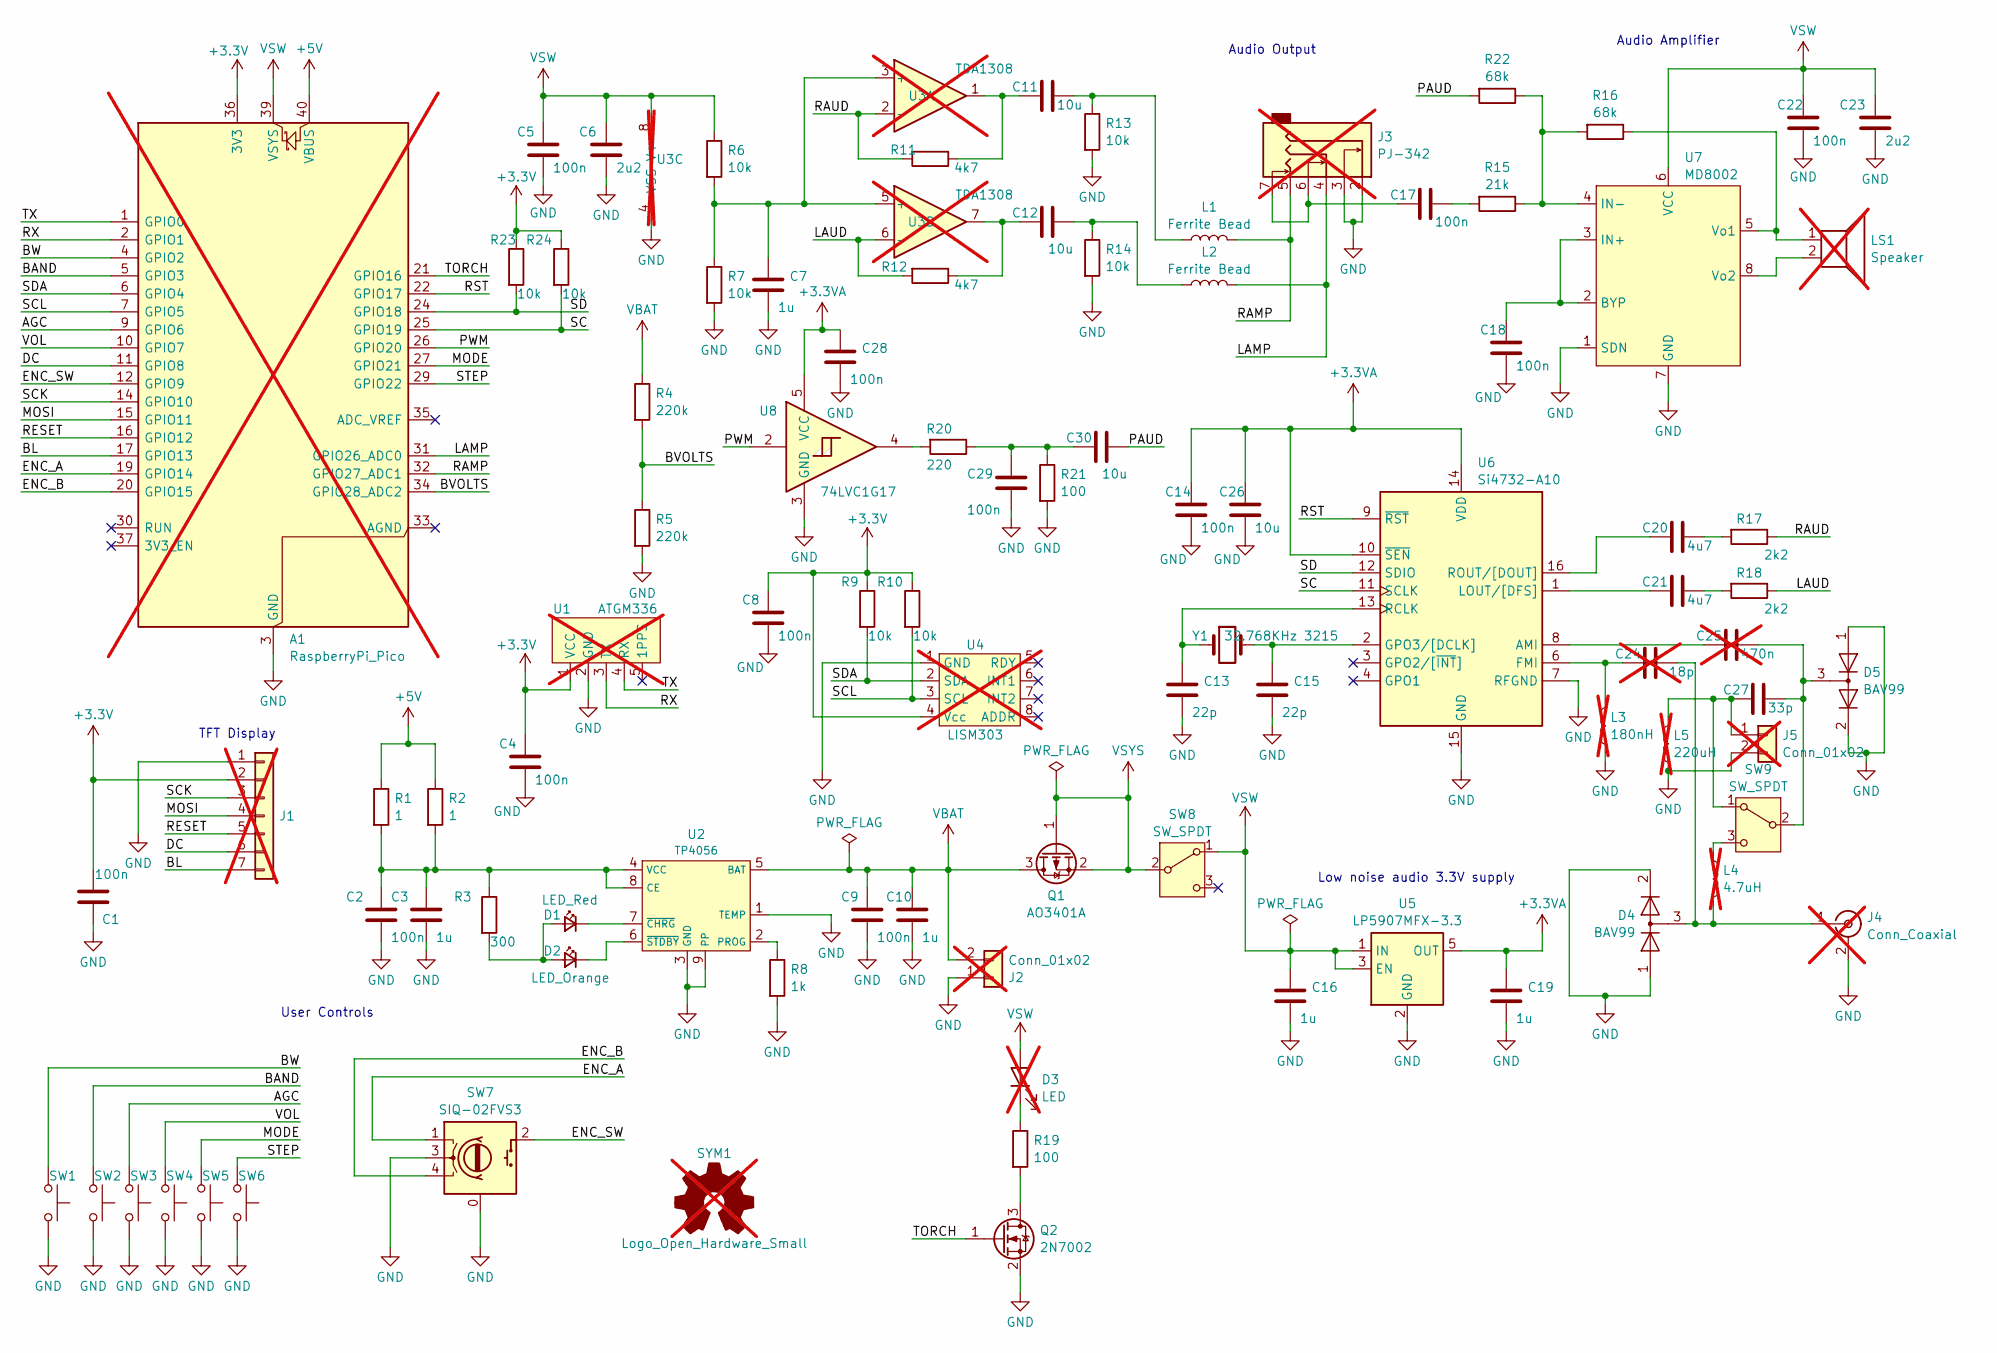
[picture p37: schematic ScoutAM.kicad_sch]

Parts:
A1: RaspberryPi_Pico; RPi_Pico_SMD_TH; not fitted
C1, C2, C4, C5, C8, C9, C14, C17, C18, C22, C28, C29: 100n; C_0603_1608Metric; LCSC C14663
C3, C7, C10, C16, C19: 1u; C_0603_1608Metric
C6, C23: 2u2; C_0603_1608Metric
C11, C12, C26, C30: 10u; C_0603_1608Metric
C13, C15: 22p; C_0603_1608Metric
C20, C21: 4u7; C_0603_1608Metric
C24: 18p; C_0603_1608Metric; not fitted
C25: 470n; C_0603_1608Metric; not fitted
C27: 33p; C_0603_1608Metric
D1: LED_Red; LED_0603_1608Metric
D2: LED_Orange; LED_0603_1608Metric
D3: LED; LED_D5.0mm_Horizontal_O6.35mm_Z9.0mm; not fitted
D4, D5: BAV99; SOT-23
J1: Conn_01x07; 240LCD; not fitted
J2: Conn_01x02; JST_PH_S2B-PH-SM4-TB_1x02-1MP_P2.00mm_Horizontal; not fitted
J3: PJ-342; Jack_3.5mm_PJ342_Horizontal; not fitted
J4: Conn_Coaxial; SMA_Samtec_SMA-J-P-H-ST-EM1_EdgeMount; not fitted
J5: Conn_01x02; PinHeader_1x02_P2.54mm_Horizontal; not fitted
L1, L2: Ferrite Bead; L_0603_1608Metric
L3: 180nH; L_0603_1608Metric; not fitted
L4: 4.7uH; L_0603_1608Metric; not fitted
L5: 220uH; L_0603_1608Metric; not fitted
LS1: Speaker; 30mm_Speaker; not fitted
Q1: AO3401A; SOT-23
Q2: 2N7002; SOT-23
R1, R2: 1; R_0805_2012Metric
R3: 300; R_0603_1608Metric
R4, R5: 220k; R_0603_1608Metric
R6, R7, R9, R10, R13, R14, R23, R24: 10k; R_0603_1608Metric
R8: 1k; R_0603_1608Metric
R11, R12: 4k7; R_0603_1608Metric
R15: 21k; R_0603_1608Metric
R16, R22: 68k; R_0603_1608Metric
R17, R18: 2k2; R_0603_1608Metric
R19: 100; R_2512_6332Metric
R20: 220; R_0603_1608Metric
R21: 100; R_0603_1608Metric
SW1, SW2, SW3, SW4, SW5, SW6: B3FS; SW_Push_1P1T_NO_6x6mm_H9.5mm
SW7: SIQ-02FVS3; SIQ-02FVS3_Rotary_Encoder
SW8, SW9: SW_SPDT; SW_Slide_SPDT_Angled_CK_OS102011MA1Q
SYM1: Logo_Open_Hardware_Small; OSHW-Logo_11.4x12mm_SilkScreen; not fitted
U1: ATGM336; not fitted
U2: TP4056; SOIC-8-1EP_3.9x4.9mm_P1.27mm_EP2.29x3mm
U3: TDA1308; SO-8_3.9x4.9mm_P1.27mm; not fitted
U4: LISM303; not fitted
U5: LP5907MFX-3.3; SOT-23-5
U6: Si4732-A10; SOIC-16_4.55x10.3mm_P1.27mm
U7: MD8002; SO-8_3.9x4.9mm_P1.27mm
U8: 74LVC1G17; SOT-23-5
Y1: 32.768KHz 3215; Crystal_SMD_3215-2Pin_3.2x1.5mm

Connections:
+3.3V: A1.36 (3V3), C1.2, C4.1, C8.1, J1.2, R9.1, R10.1, R23.1, R24.1, U1.1 (VCC), U4.4 (Vcc)
+3.3VA: C14.1, C19.1, C26.1, C28.1, U5.5 (OUT), U6.10 (~SEN), U6.14 (VDD), U8.5 (VCC)
+5V: A1.40 (VBUS), R1.1, R2.1
/AGC: A1.9 (GPIO6), SW3.1
/BAND: A1.5 (GPIO3), SW2.1
/BL: A1.17 (GPIO13), J1.7
/BVOLTS: A1.34 (GPIO28_ADC2), R4.2, R5.1
/BW: A1.4 (GPIO2), SW1.1
/DC: A1.11 (GPIO8), J1.6
/ENC_A: A1.19 (GPIO14), SW7.1 (A)
/ENC_B: A1.20 (GPIO15), SW7.4 (B)
/ENC_SW: A1.12 (GPIO9), SW7.2 (S1)
/LAMP: A1.31 (GPIO26_ADC0), J3.4, L2.2
/LAUD: R12.2, R18.1, U3.6 (-)
/MODE: A1.27 (GPIO21), SW5.1
/MOSI: A1.15 (GPIO11), J1.4
/PAUD: C30.1, R22.2
/PWM: A1.26 (GPIO20), U8.2
/RAMP: A1.32 (GPIO27_ADC1), J3.5, L1.2
/RAUD: R11.2, R17.1, U3.2 (-)
/RESET: A1.16 (GPIO12), J1.5
/RST: A1.22 (GPIO17), U6.9 (~RST)
/RX: A1.2 (GPIO1), U1.3 (TX)
/SC: A1.25 (GPIO19), R24.2, U6.11 (SCLK)
/SCK: A1.14 (GPIO10), J1.3
/SCL: A1.7 (GPIO5), R10.2, U4.3 (SCL)
/SD: A1.24 (GPIO18), R23.2, U6.12 (SDIO)
/SDA: A1.6 (GPIO4), R9.2, U4.2 (SDA)
/STEP: A1.29 (GPIO22), SW6.1
/TORCH: A1.21 (GPIO16), Q2.1 (G)
/TX: A1.1 (GPIO0), U1.4 (RX)
/VOL: A1.10 (GPIO7), SW4.1
GND: A1.3 (GND), A1.8 (GND), A1.13 (GND), A1.18 (GND), A1.23 (GND), A1.28 (GND), A1.38 (GND), C1.1, C2.2, C3.2, C4.2, C5.2, C6.1, C7.2, C8.2, C9.2, C10.2, C13.2, C14.2, C15.2, C16.2, C18.2, C19.2, C22.2, C23.1, C26.2, C28.2, C29.2, D4.1 (K), D4.2 (A), D5.1 (K), D5.2 (A), J1.1, J2.1, J3.2, J3.3, J4.2 (Ext), J5.2, L3.1, L5.1, Q2.2 (S), R5.2, R7.2, R8.2, R13.2, R14.2, R21.2, SW1.2, SW2.2, SW3.2, SW4.2, SW5.2, SW6.2, SW7.0 (MP), SW7.3 (C), U1.2 (GND), U2.1 (TEMP), U2.3 (GND), U2.9 (PP), U3.4 (VSS), U4.1 (GND), U5.2 (GND), U6.7 (RFGND), U6.15 (GND), U7.1 (SDN), U7.7 (GND), U8.3 (GND)
unnamed: C11.1, L1.1, R13.1
unnamed: C11.2, R11.1, U3.1
unnamed: C12.1, L2.1, R14.1
unnamed: C12.2, R12.1, U3.7
unnamed: C17.1, R15.2
unnamed: C17.2, J3.6, J3.7
unnamed: C20.1, R17.2
unnamed: C21.1, R18.2
unnamed: C29.1, C30.2, R20.1, R21.1
unnamed: D1.2 (A), D2.2 (A), R3.2
unnamed: D1.1 (K), U2.7 (~CHRG)
unnamed: D2.1 (K), U2.6 (~STDBY)
unnamed: D3.1 (K), R19.1
unnamed: C24.1, D4.3 (K), J4.1 (In), L4.2
unnamed: C27.2, J5.1, L5.2, SW9.1 (A)
unnamed: Q2.3 (D), R19.2
unnamed: R20.2, U8.4
unnamed: C25.1, C27.1, D5.3 (K), SW9.2 (B)
unnamed: L4.1, SW9.3 (C)
unnamed: C2.1, C3.1, R1.2, R2.2, R3.1, U2.4 (VCC), U2.8 (CE)
unnamed: R8.1, U2.2 (PROG)
unnamed: C7.1, R6.2, R7.1, U3.3 (+), U3.5 (+)
unnamed: C25.2, U6.8 (AMI)
unnamed: C24.2, L3.2, U6.6 (FMI)
unnamed: C15.1, U6.2 (GPO3/[DCLK]), Y1.2
unnamed: C21.2, U6.1 (LOUT/[DFS])
unnamed: C13.1, U6.13 (RCLK), Y1.1
unnamed: C20.2, U6.16 (ROUT/[DOUT])
unnamed: C18.1, U7.2 (BYP), U7.3 (IN+)
unnamed: R15.1, R16.2, R22.1, U7.4 (IN-)
unnamed: LS1.1, R16.1, U7.5 (Vo1)
unnamed: LS1.2, U7.8 (Vo2)
VBAT: C9.1, C10.1, J2.2, Q1.3 (D), R4.1, U2.5 (BAT)
VSW: A1.39 (VSYS), C5.1, C6.2, C16.1, C22.1, C23.2, D3.2 (A), R6.1, SW8.1 (A), U3.8 (V+), U5.1 (IN), U5.3 (EN), U7.6 (VCC)
VSYS: Q1.1 (G), Q1.2 (S), SW8.2 (B)

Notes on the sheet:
Audio Amplifier
Audio Output
TFT Display
Low noise audio 3.3V supply
User Controls

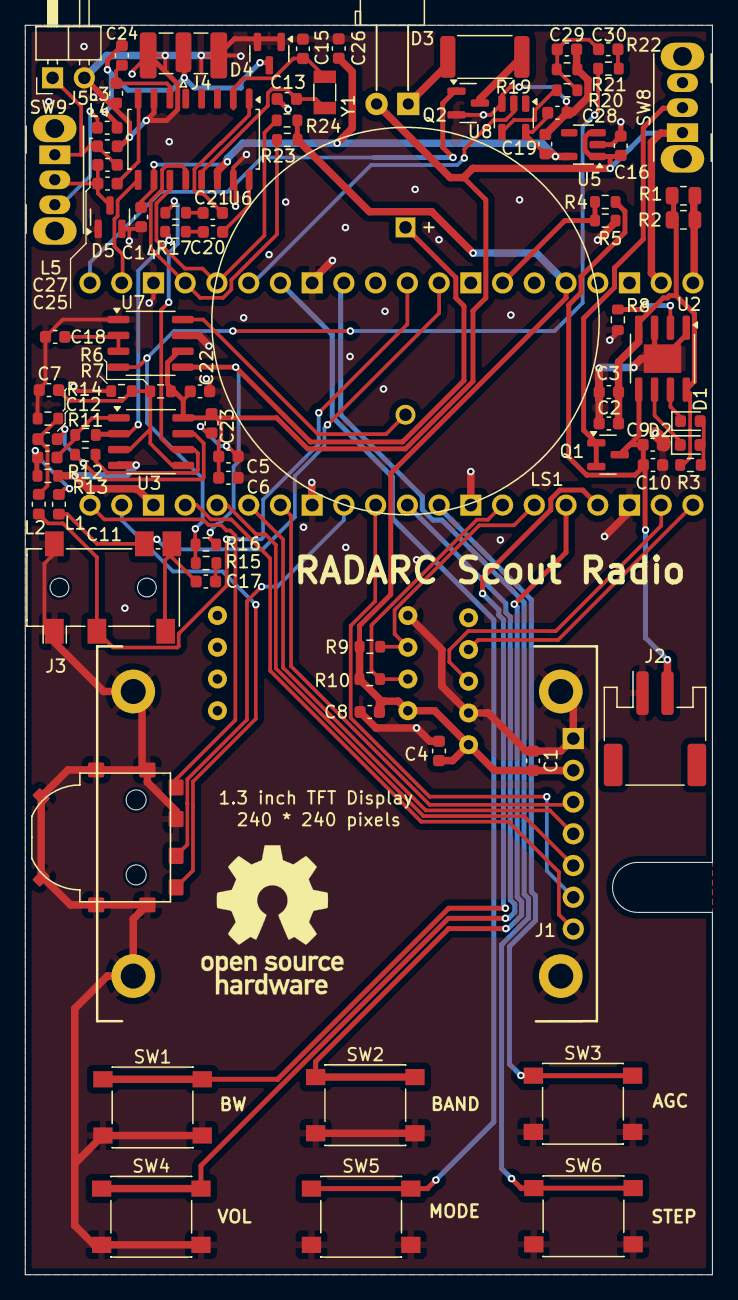
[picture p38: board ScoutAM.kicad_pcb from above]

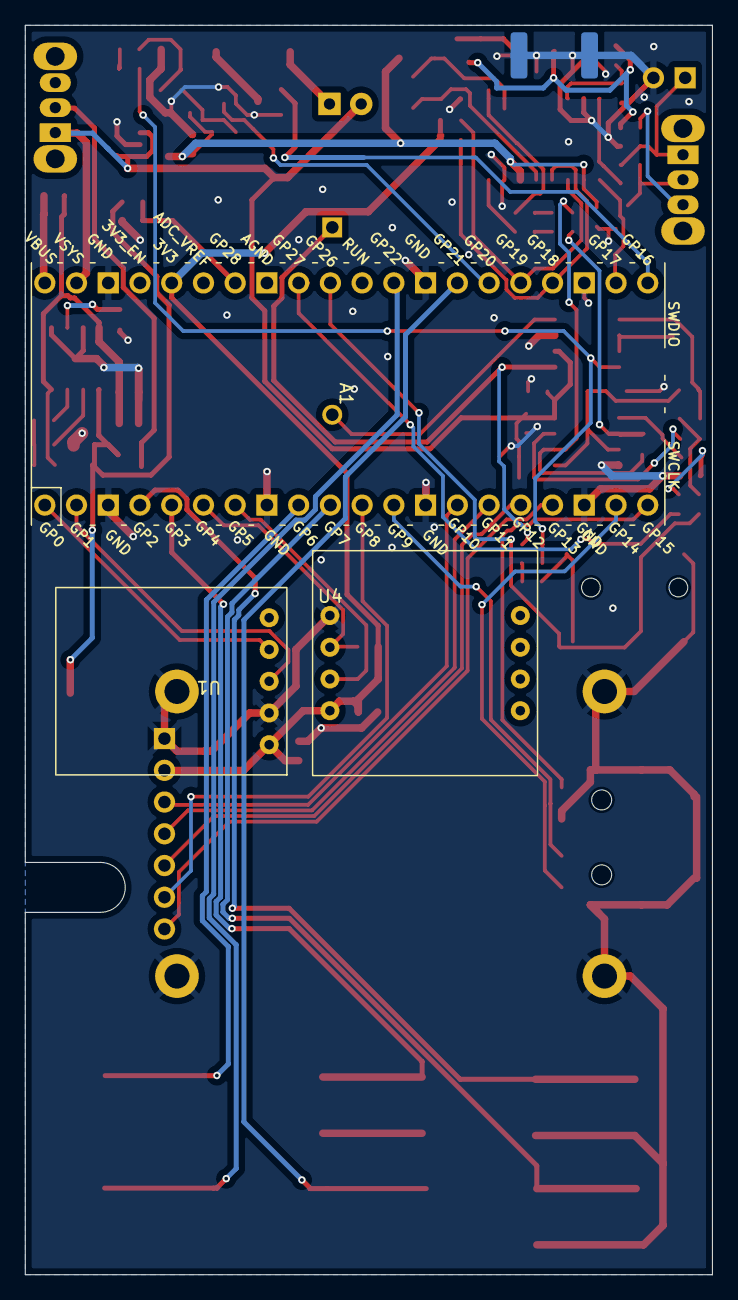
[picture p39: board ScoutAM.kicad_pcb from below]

Board: 2 copper layers, 55.0 x 100.0 mm, 92 parts (3 on the bottom side), 68 nets.

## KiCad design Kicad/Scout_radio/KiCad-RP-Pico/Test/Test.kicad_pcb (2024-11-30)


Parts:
J1, J2: Conn_01x20; PinSocket_1x20_P1.00mm_Vertical
J3: Conn_01x03; PinSocket_1x03_P1.00mm_Vertical
U1: Pico; RPi_Pico_SMD_TH

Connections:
GND: J1.3, J1.8, J1.13, J1.18, J2.3, J2.13, J2.18, J3.2, U1.3 (GND), U1.8 (GND), U1.13 (GND), U1.18 (GND), U1.23 (GND), U1.28 (GND), U1.38 (GND), U1.42 (GND)
unnamed: J1.1, U1.1 (GPIO0)
unnamed: J1.2, U1.2 (GPIO1)
unnamed: J1.4, U1.4 (GPIO2)
unnamed: J1.5, U1.5 (GPIO3)
unnamed: J1.6, U1.6 (GPIO4)
unnamed: J1.7, U1.7 (GPIO5)
unnamed: J1.9, U1.9 (GPIO6)
unnamed: J1.10, U1.10 (GPIO7)
unnamed: J1.11, U1.11 (GPIO8)
unnamed: J1.12, U1.12 (GPIO9)
unnamed: J1.14, U1.14 (GPIO10)
unnamed: J1.15, U1.15 (GPIO11)
unnamed: J1.16, U1.16 (GPIO12)
unnamed: J1.17, U1.17 (GPIO13)
unnamed: J1.19, U1.19 (GPIO14)
unnamed: J1.20, U1.20 (GPIO15)
unnamed: J2.1, U1.40 (VBUS)
unnamed: J2.2, U1.39 (VSYS)
unnamed: J2.4, U1.37 (3V3_EN)
unnamed: J2.5, U1.36 (3V3)
unnamed: J2.6, U1.35 (ADC_VREF)
unnamed: J2.7, U1.34 (GPIO28_ADC2)
unnamed: J2.8, U1.33 (AGND)
unnamed: J2.9, U1.32 (GPIO27_ADC1)
unnamed: J2.10, U1.31 (GPIO26_ADC0)
unnamed: J2.11, U1.30 (RUN)
unnamed: J2.12, U1.29 (GPIO22)
unnamed: J2.14, U1.27 (GPIO21)
unnamed: J2.15, U1.26 (GPIO20)
unnamed: J2.16, U1.25 (GPIO19)
unnamed: J2.17, U1.24 (GPIO18)
unnamed: J2.19, U1.22 (GPIO17)
unnamed: J2.20, U1.21 (GPIO16)
unnamed: J3.1, U1.43 (SWDIO)
unnamed: J3.3, U1.41 (SWCLK)


Board: 2 copper layers, 43.0 x 65.0 mm, 4 parts (0 on the bottom side), 36 nets.

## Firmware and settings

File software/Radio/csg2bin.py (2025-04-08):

#!/usr/bin/env python3

""" convert patch.csg to compressed binary file """
#
# create patchcomp.bin from patch.csg
# "compressed" version of patch.csg
#
import os

# SSB download patch specials
cmd_0x15 = (0, 128, 371, 374, 376, 378, 380, 383, 385, 388, 390, 392, 394, 396,
            398, 400, 402, 404, 593, 616, 650, 661, 757, 869, 872, 915, 942,
            945,  948, 985, 994, 999,  1002, 1004, 1007, 1010, 1013, 1015,
            1019, 1022, 1040, 1063, 1069, 1074, 1076, 1078, 1081, 1084, 1088,
            1091, 1093, 1097, 1099, 1102, 1104)

# SSB download patch
sb_patch_content = (
0x00, 0x03, 0x74, 0x0B, 0xD4, 0x84, 0x60,
0x6F, 0xAE, 0x6C, 0xF9, 0xBB, 0x84, 0xA2,
0x65, 0xB1, 0x4B, 0xF6, 0x72, 0x01, 0x1A,
0x21, 0xE8, 0x5A, 0xD8, 0xD6, 0x04, 0x73,
0x5E, 0x2C, 0x22, 0x6E, 0xC4, 0xE9, 0xB5,
0x8B, 0x81, 0x9A, 0x1E, 0xE4, 0x87, 0xC9,
0x9E, 0x7B, 0x17, 0x52, 0x6D, 0xAD, 0xE3,
0xE5, 0x8B, 0x04, 0xA7, 0x2E, 0x99, 0x6A,
0x32, 0xAA, 0x99, 0x97, 0xCC, 0xA6, 0x5B,
0x15, 0x79, 0x56, 0x48, 0x01, 0x63, 0xB1,
0xDF, 0x54, 0x27, 0x06, 0x57, 0x06, 0x53,
0x8C, 0xA6, 0x27, 0xAA, 0x66, 0x89, 0x03,
0x18, 0x51, 0x7E, 0xFB, 0x67, 0xD3, 0xCE,
0xDD, 0x3F, 0xFD, 0x3D, 0x1F, 0x47, 0x84,
0x01, 0xF3, 0x85, 0x6E, 0xF8, 0x3B, 0x79,
0x2B, 0x0C, 0x90, 0x4B, 0x67, 0x46, 0x7D,
0x54, 0x88, 0xFD, 0xD6, 0x12, 0xE5, 0xE7,
0x48, 0xF2, 0x0E, 0xDB, 0x99, 0x4D, 0x71,
0xA5, 0x40, 0x68, 0xD9, 0xC9, 0x59, 0x39,
0xE4, 0x75, 0x20, 0x1C, 0xE9, 0xB1, 0xF5,
0x01, 0x3C, 0x19, 0xBB, 0x60, 0xF7, 0xFA,
0x6B, 0x1E, 0x68, 0x9F, 0x19, 0xB6, 0xED,
0x14, 0x0F, 0x56, 0xBC, 0xC1, 0x34, 0xCB,
0x00, 0x9D, 0x43, 0xD4, 0x0F, 0xF3, 0x62,
0x9C, 0x9D, 0xF7, 0x8B, 0x9D, 0x53, 0x3A,
0x8D, 0x2F, 0x3D, 0xDE, 0x3D, 0x38, 0x31,
0x03, 0x9B, 0xC7, 0xC1, 0x59, 0xE9, 0xD1,
0x75, 0x88, 0x8D, 0x36, 0x58, 0x86, 0x70,
0x4E, 0x5B, 0x9E, 0xD0, 0xDB, 0xCB, 0xF7,
0xEA, 0x1F, 0xDB, 0xA5, 0x3B, 0xB3, 0xBD,
0x6B, 0xBC, 0xF3, 0x70, 0x65, 0xD5, 0x17,
0x0F, 0x64, 0x15, 0x24, 0x20, 0xD5, 0xB8,
0x7B, 0x0D, 0x27, 0x29, 0x85, 0x88, 0x1F,
0x58, 0x22, 0x57, 0x4F, 0x09, 0xC0, 0x4D,
0xD6, 0xE4, 0xC6, 0xB5, 0x3A, 0x37, 0x33,
0x27, 0xBB, 0x6A, 0x14, 0x69, 0x03, 0x1B,
0xED, 0xA8, 0xC3, 0x43, 0xE8, 0xEA, 0xDE,
0x41, 0x06, 0x25, 0xC5, 0xC8, 0x3C, 0xBF,
0x32, 0xB2, 0xA7, 0xDD, 0x22, 0xC2, 0xE9,
0xCA, 0x84, 0xF2, 0xC0, 0x26, 0x7C, 0x78,
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

def decodecompbin(cmpbytes):
    """ for verification purposes """
    length = int(cmpbytes[0])

    specials_hex_15=[]
    for i in range(0,length*2,2):
        special_idx = i + 1
        special = int.from_bytes(cmpbytes[special_idx:special_idx+2],"big")
        specials_hex_15.append(special)

    the_rest = cmpbytes[1 + length*2:]

    assert len(the_rest) % 7 == 0

    return (length, specials_hex_15, the_rest)

def readcsgfile(csgfilespec):
    """ internalise patch.csg """
    result = bytearray()
    specials_hex_15 = []
    line_number = 0

    with open(csgfilespec, "r", encoding="utf-8") as csgfile:
        for line in csgfile.readlines():
            if line.startswith("#"):
                continue

            chunkstrlist = line.strip().split(',')

            chunk = [int(item, 16) for item in chunkstrlist]

            result.extend(bytearray(chunk[1:]))

            if chunk[0] == 0x15:
                specials_hex_15.append(line_number)

            line_number += 1

    return (result, specials_hex_15)

def writebinfile(outfilename, specials_hex_15, compressed_body):
    """ write pseudo-compressed binary file """
    header=bytearray([len(specials_hex_15)])

    for special in specials:
        # endian is arbitrary
        #print(d.to_bytes(2, "big"))
        header.extend(special.to_bytes(2, "big"))

    #print(result)
    finalbytearray = header + compressed_body

    # sanity
    (special_len, specials_list_decoded, _decoded_body) = decodecompbin(finalbytearray)

    assert special_len == len(specials_hex_15)
    assert specials_hex_15 == specials_list_decoded

    #print(special_len, specials)

    with open(outfilename,"wb") as compressed_binpatchfile:
        compressed_binpatchfile.write(finalbytearray)


if __name__ == "__main__":
    INFILE = "patch.csg"
    outfile = os.path.splitext(INFILE)[0]+"comp.bin"

    USE_SSB_PATCH_HERE = False

    if USE_SSB_PATCH_HERE:
        body = bytearray(sb_patch_content)
        specials = cmd_0x15
    else:
        # internalise patch.csg
        (body, specials) = readcsgfile(INFILE)

    assert len(specials) < 256
    #print([hex(x) for x in body])

    #
    # create a binary file:
    # -- number of "specials" as a byte
    # -- specials as 16 bit quantities
    # -- seven byte arrays consecutively as the body
    #
    writebinfile(outfile, specials, body)

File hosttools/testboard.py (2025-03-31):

"""
get a python command line on USB serial port and synchronise files
for MicroPython and CircuitPython devices
"""

import sys
import os
import serial
import pexpect
import pexpect.fdpexpect
import sysdetect
import filemanager
import fileops

#
# beginnings of proper logging
#
VERBOSE_SEND_REPL = False
VERBOSE_SEND_REPL_RESPONSE = False
VERBOSE_SEND_RSHELL = False
VERBOSE_SEND_RSHELL_RESPONSE = False

#
# handy formatter
#
def formatoutput(output):
    """ format output from target board """
    for line in output.split("\r\n"):
        print(line)


class TestBoard:
    """ Base class for MicroPython and CircuitPython scout radio boards """
    def __init__(self, serialport, file_operations):
        self.m_child = None
        self.m_ostype = None

        #
        # Create a generic file manager with board-type specific
        # file operations (i.e. Micro Python or Circuit Python)
        # using the file operations object created in the board-type specific
        # test board constructor.
        #
        self.m_filemanager = filemanager.FileManager(file_operations)

        #
        # serial port scaffold stuff
        #
        self.m_ser = None
        self.m_serialportname = serialport

        #
        # TODO serial port speed hardcoded to 115200 for now
        #
        self.m_serialspeed = 115200

        #
        # record whether we have been initialised
        #
        self.m_initialised = False

    def serialportname(self):
        """ return serial port name """

        return self.m_serialportname

    def open_serial(self):
        """ open the serial device if necessary """

        if not self.m_ser:
            self.m_ser = serial.Serial()
            self.m_ser.baudrate = self.m_serialspeed
            self.m_ser.port = self.m_serialportname

            try:
                self.m_ser.open()

            except serial.SerialException as excep:
                sys.exit(f"{excep}")

        self.m_ser.reset_input_buffer()


    def close_serial(self):
        """ close the serial device """
        self.m_ser.close()
        self.m_ser = None

    def create_pexpect_child(self, send_cr=True):
        """ create a pexpect child object with python repl """

        self.open_serial()

        self.m_child = pexpect.fdpexpect.fdspawn(self.m_ser, timeout=5)

        if send_cr:
            # can't use sendrepl here as that potentially switches session type
            self.m_child.sendline("\r\n")


    def sethomedir(self, homedir):
        """ configure the home directory for the component """
        self.m_filemanager.set_target_homedir(homedir)


    def setfiles(self, targetfiles):
        """ configure the list of host python files to be run on target """

        self.m_filemanager.setfiles(targetfiles)

    def sendrepl(self, cmd, expect_repl=True):
        """ code not used, here just for pylint """

        # keep pylint from grumping
        assert self
        assert cmd
        assert expect_repl

        # should not be called
        assert False

        # pylint, can't get here anyway
        return ""


    def sendreplbase(self, cmd, expect_repl=True):
        """
            Base class code to send a command to MicroPython
            or CircuitPython repl. Tweaks to the invocation/behaviour
            are in the derived classes in sendrepl.

            Not to be used directly, generally.
        """

        if VERBOSE_SEND_REPL:
            print(f">>> {cmd}")

        self.m_child.sendline(cmd)

        # don't expect repl to come back to us - eg. autorun code.py
        if not expect_repl:
            return ""

        # timeout long enough for download patch etc.
        self.m_child.expect(">>> ", timeout = 8)

        output = self.m_child.before.decode()

        if VERBOSE_SEND_REPL_RESPONSE:
            print(output)

        if "Traceback" in output and not "KeyboardInterrupt:" in output:
            #
            # dump the traceback from target
            #
            print(output)

            #
            # force failure - we have a traceback from target.
            # Could use False here but hopefully what's below
            # is more descriptive of what's gone wrong.
            #
            assert "Traceback" not in output

        #
        # Don't echo the command sent.
        # Return the second line of output onwards.
        # The strip is debatable.
        #
        return "\r\n".join(output.split("\r\n")[1:]).strip()


    def identify(self):
        """ print the scout radio os/python type """
        self.sendrepl("import sys")
        ostype = self.sendrepl("print(sys.implementation.name)")
        print(f"{ostype} board created")
        self.m_ostype = ostype


    def ostype(self):
        """
        return string describing the type of python running on target.
        return None if the board is not initialised.
        """
        return self.m_ostype


    def get_control(self):
        """
        send control c to target if unresponsive
        """

        #
        # TODO/latent BUG.
        # Not sure why we can't just unconditionally
        # throw a control-c at target eg. even if it
        # doesn't need interrupting i.e. is at the
        # usual python repl prompt >>>.
        #
        # If we do, "python testboard.py" with a board
        # present fails the board.identify() invocation.
        #
        # Timeout used below is totally arbitrary to
        # determine whether the prompt is there or not.
        #
        try:
            self.m_child.expect(">>> ", timeout = 0.1)

        except pexpect.exceptions.TIMEOUT:
            self.ctrlc()


    def initialise(self, expect_repl=True, do_reboot=True):
        """ get the test board ready for use using the python repl
            on the (USB) serial port """
        self.create_pexpect_child()
        self.get_control()
        if do_reboot:
            self.reboot()
        self.m_filemanager.copy_files_to_target()

        #
        # a bit arbitrary
        #
        self.m_initialised = True

        # odd case for code.py
        if not expect_repl:
            return

        # homedir may necessarily not be set: eg. python testboard.py
        if self.m_filemanager.m_homedir:
            self.sendrepl("import os")
            target_homedirname = os.path.basename(self.m_filemanager.m_homedir)
            self.sendrepl(f"os.chdir(\"/{target_homedirname}\")")


    def initialised(self):
        """ return whether we have been initialised """

        return self.m_initialised


    def revsync(self):
        """ pull files from target board back to host """

        if self.m_filemanager.m_files:
            self.create_pexpect_child()
            self.m_filemanager.copy_files_from_target()


    def reboot(self, expect_repl=True):
        """ restart the python interpreter on target by sending CTRL+D """
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

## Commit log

2024-11-30 First commit of Kicad files
    [1.3 TFT IPS.stp, 18650 Battery Holder v5.step, 3214G.stp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]
2024-11-30 Update README.md to include GPS and compass
    [ScoutAM.kicad_pcb]
2024-12-12 Added software folder
    Added software folder with CircuitPython for testing
    Fixed hardware cross of SDA and SCL to Si4732
    [Display Scout.stl, ScoutAM.kicad_pcb, ScoutAM.kicad_sch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]
2024-12-14 Tidy Up Software folders
    Add folders to software
    Add GPS tests
    Add Magnetometer and accelerometer tests
    Add Morse sending
2025-02-04 update to latest si4735 driver from RADARC si4735 repo
2025-02-25 Added encoder for tuning
2025-03-10 first cut at installer
2025-03-10 factor out FileOPs objects for Circuit Python and Micro Python
2025-03-10 bomb on failure immediately with sysinstall
    [sysinstall.py]
2025-03-11 cleanup; fix some pylint whining
    [testboard.py]
2025-03-11 make reboot method on testboard a thing
    [testboard.py]
2025-03-11 cleanup (switch sense of test to be positive), bomb early if source file doesn't exist, comments
    [testboard.py]
2025-03-11 fix ensuredir etc. for Micro Python; beginnings of copy files from target to source
    [testboard.py]
2025-03-11 add missing file install.py at top level which installs code.py typically
    [install.py]
2025-03-11 lose a couple of lines
2025-03-11 factor out get_target_fullpath method avoiding duplicated code
    [testboard.py]
2025-03-11 tweaks (fixes) to allow testboard.py to be run standalone
    [testboard.py]
2025-03-11 case consistency
2025-03-11 beginnings of installer for GPS - doesn't work due to adafruit_gps not being found
    [gps-serial.py, install.py]
2025-03-11 factor out boarddetect.py file from testboard.py
2025-03-11 better naming, I've used boarddetect elsewhere...
2025-03-11 improve verbose printing control: beginnings of proper logging
2025-03-12 implement TODO get rid of self.i2c
2025-03-12 simplify pylint whine workarounds
    [testboard.py]
2025-03-14 fix setting of directory on target
    [testboard.py]
2025-03-16 change how serial port usage is done for MicroPython. Make it the same as CircuitPython switching to rshell app when we need to.
2025-03-16 example of how to run app on powerup
2025-03-16 method to start app on power up automatically, code.py main.py etc.
2025-03-16 fix auto run file member variable
    [testboard.py]
2025-03-16 shell script to help installing RPI-Pico
2025-03-17 pylint - useless sendrepl on circuit python board
2025-03-17 fix initial CTRLC, return a string already decoded from send_repl
    [testboard.py]
2025-03-17 type consistency; fix comment
    [testboard.py]
2025-03-18 deal with MicroPython reboot behaviour being different to CircuitPython. Stop sendrepl echoing the command in its output.
    [testboard.py]
2025-03-18 fix bug where pexpect gets confused after installing files on MicroPython. Not fully understood. Flush serial port when opening it. Reboot on MicroPython after installing files as we don't know what 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
    [testboard.py]
2025-03-18 i2c patch download speed investigation: addi explicit speeds to i2c
2025-03-18 investigate tardy i2c - run with time python testpatchdownload.py [--install]
2025-03-18 remove useless fw version printing
2025-03-18 Revert "remove useless fw version printing"
    This reverts commit 968ff2db444d9c0b3ad1485090b0a1ae300c2647.
    [testpatchdownload.py]
2025-03-18 wait for circuit python filesystem to come up rather than failing miserably
    [sysdetect.py, testboard.py]
2025-03-18 wait a bit longer for circuit python filesystem
2025-03-19 test the short SSB patch - doesn't seem to work
    [csg2bin.py]
2025-03-19 fix stuff happening as part of side effect of print
    [testpatchdownload.py]
2025-03-19 remove noise from patchPowerUp
    [testpatchdownload.py]
2025-03-19 introduce MIN_DELAY_WAIT_DLPATCH so we can tweak patch download i2c wait independently
2025-03-19 fix output from sendrepl. Don't destroy formatting done with CR/LF but still keep the final result stripped (for now)
    [testboard.py]
2025-03-20 run i2c at 1MHz in tests
2025-03-20 microcontroller overclock circuit python only
2025-03-20 Fix broken SSB bandwidth
    [radio.py, radioapp.py, si47xx.py]
2025-03-20 pylint, fix tests a bit
    [testpatchdownload.py]
2025-03-20 test.py -> si47xx_test.py, testpatchdownload.py -> si47xx_testpatchdownload.py as these test files are testing si47xx.py. Both run on Micro Python and Circuit Python ok.
2025-03-20 for circuit python, unconditionally remove code.py when tools in use. Perhaps a bit rude but if you're using the tools, you want access to the system.
2025-03-21 look for rw mount no longer necessary
2025-03-21 plug a few holes and race conditions
2025-03-21 always reset_input_buffer() on serial open
    [testboard.py]
2025-03-21 fix up si47xx tests to use singleton board, simplify a bit, add beginnings of radio_test.py
    [harness.py, radio.py, radio_test.py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]
2025-03-21 Revert "minor optimisation"
    This reverts commit 5d6c2fed9b526d2dce616b510ab36ce138b99b52.
    [radio.py]
2025-03-21 remove print and i2c write happening as side effect
2025-03-22 add --force to delete main.py on startup for Micro Python boards
2025-03-24 fix force default value
    [testboard.py]
2025-03-24 stuff mountpoint and auto run file in fileops object
2025-03-24 make what we can private in micropython derived test board object
2025-03-25 use self.close_expect_serial made for the job in the base class in the micropython test board. Make it protected in the base class. Fix out of date comments.
    [testboard.py]
2025-03-26 Improving tuning, keep track of frequency
2025-03-26 use argparse and thus add --help; towards issue #10
    [installib.py]
